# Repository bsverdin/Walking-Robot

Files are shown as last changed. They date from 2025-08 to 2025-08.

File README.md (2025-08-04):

# Walking-Robot
Walking robots for Science fair
In this repository, There are the codes for multiple robots: Model STU (initial prototype focused solely on energy-efficnecy), Model VINNIE (second prototype with a camera for easy operation), and MODEL TERRA (last prototype with a ultrasonic distance sensor).
All the walking robots operate on the Arduino IDE software system.
Model STU only uses an Arduino Uno board
Model VINNIE and MODEL TERRA uses two Espressif boards: The ESP32-CAM AI THINKER and the ESP32-WROOM

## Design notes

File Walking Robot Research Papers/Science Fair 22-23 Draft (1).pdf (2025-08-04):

# ABSTRACT

## The Illinois Junior Academy of Science Electronics

CATEGORY ________________________________________________________STATE REGION # ________________ Lane Tech College Prep

SCHOOL __________________________________________________________IJAS SCHOOL # _________________ Chicago / 60618 7735345400

CITY/ZIP __________________________________________________________SCHOOL PHONE ________________ Mr. Daniel Law

SPONSOR _________________________________________________________

CHECK ONE: ☐ EXPERIMENTAL INVESTIGATION [ ] ☐ DESIGN INVESTIGATION
(Choice will determine rubric used for assessment) Bianca Verdin

NAME OF EXHIBITOR * _______________________________________________GRADE________________________

NAME OF EXHIBITOR ________________________________________________GRADE _______________________

* If this project is awarded a monetary prize, the check will be written in this scientist’s name and it will be his/her responsibility to distribute the prize money equally among all participating exhibitors. Design of an Energy-Efficient Walking Robot

PROJECT TITLE ___________________________________________________________________________________ a) Purpose - The purpose of this design investigation was to create a walking quadruped robot that was energy-efficient. If walking robots were more energy efficient, they would be used for more exploration, search and rescue, and inspections. b) Procedure - The body of the robot was created using a 1 cm thick PVC board. After constructing the body, all the electronic components were screwed into the body. Then, using the code for last year, by implementing it to all the motors, the servos were then programmed to move in a specific gait. The robot's energy intake and distance traveled were used to calculate the Cost of Transportation (CoT) of the robot. c) Conclusion - While Design A may be more energy efficient, Design B is much more reliable and traveled longer distances than Design A. Design B was relatively energy efficient with a median cost of transportation of .14.

1. Limit Abstract to 3 paragraphs (250 words or less). Include: a) Purpose– what you set out to investigate; b) Procedure – how you did it;
c) Conclusion – based on your results. Label each paragraph.
2. Must be typed, single-spaced, on the front side of this form. DO NOT write on back side of this form.
3. Three (3) copies of your COMPLETE paper are required at the State Science Project Exposition. Four (4) copies of your COMPLETE paper are required for the State Paper Session Competition.

The above form must be duplicated. (Student-generated forms must be in essentially the same format.)
This form MUST be displayed on the front of the exhibitor’s display board. It may be reduced to fit on a half sheet of paper. (Print at 75% reduction) Displayed abstract cannot be smaller than 8.5 inches (vertical) x 5.5 inches (horizontal).

3

3001

(ALL ITEMS LISTED MUST BE TYPED)

SAVE Off | PRINT Off

SAFETY SHEET

The Illinois Junior Academy or Science Directions: The student is asked to read this introduction carefully, fill out the bottom of this sheet. The science teacher and/or advisor must sign in the indicated space. By signing this sheet, the sponsor
assumes all responsibilities related to this project.

Safety and the Student: Experimentation or design may involve an element of risk or injury to the student, test subjects and to others. Recognition of such hazards and provision for adequate control measures are joint responsibilities of the student and the sponsor. Some of the more common risks encountered in research al.e those of electi.ical shock, infection from pathogenic organisms, uncontrol]ed reactions of incompatible chemicals, eye injury from materials or procedures, and fire in apparatus or work area. Countering these hazards and others with suitable controls is an integral part of good scientific research. In the chart below,
list the principal hazards associated with your project, if any, and what specific precautions
you have used as safeguards. Be sure to read the entire section in the Po/I.cj/ fl,;!d P;.ocedwre A4lczj!#a/ a/ffee /J/I.iioz.a J"Hz.or .4cc}cJem); a/Sc.I.c#c.e entitled " Safety Guidelines for Experimentation" before completing this form.
Possible hazards | Precautions taken to deal with each hazard
1. Choking and hair loss are possible from
motors or power tools snagging on loose
articles or hair.
2. Overheating components could cause burns or fire.
3. Electrocution from an improper connection of wires.
4. Cuts and scratches from the pins, wires, and power tools.
5. Pedestrians and animals may hit the robot during outside testing.
1. Hair was tied back in a ponytail; no loose clothing, necklaces, or lanyards were worn, and all items with a hazard of getting caught were moved away from the motor.
2. Motors were tested in short trials no more than an hour and if the components got hot testing was immediately stopped.
3. All bent, broken, or uncovered wires were thrown away and not used to connect the motors.
4, Power tools were handled by adults only and any cuts and scratches sustained were immediately sanitized and treated.
5. Testing was immediately stopped when pedestrians or animals were spotted on the sidewalk

Please check off any other possible endorsements needed. Include these documents in your paper and on your board. Human as Test Subjects -for any projects involving humans-even surveys.
Microorganism-for any projects involving bacteria, viruses, yeasts, fimgi or protozoa -Non-Human Vcrtcbrates -for any projects involving fish, amphibians, rcpLilcs, birds or mammals
-Tissue Culture-for any proj ects involving growing eukaryotic tissues or cell cultures

Recombinant DNA-must be conducted in a regiLstered research laboratory under professi onal supervision
Use of Fircarms - including all required documents

## ±i_::tifutionwherel.esearchwasd;:,ZSZ%Xcept]:_nt°the]JAsm]esh::_:=L

*As a sponsor, I assume all responsibilities related to this project. This Sheet Must Be Typed and this form must be displayed on the front of the exhibitor's display board. Displayed Safety Sheet can not be smaller than 8.5 inches (vertical) X 5.5 inches qorizontal). Print at 75% reduction.

SAVE E | PRINT H

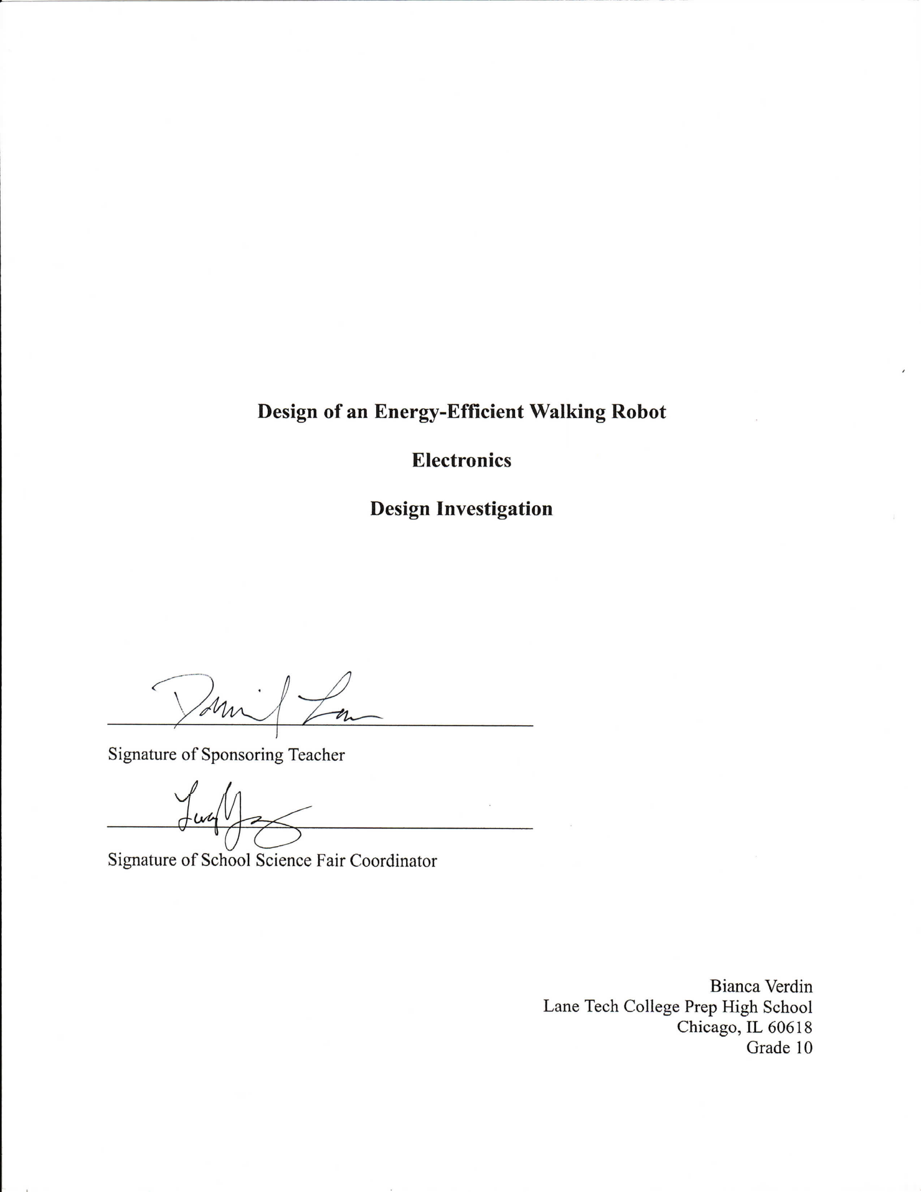
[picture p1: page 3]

### Design of an Energy-Efficient Walking Robot

Hlectronics

Design Investigation

Signature of Sponsoring Teacher

Signature of School Science Fair Coordinator

Bianca Verdin
Lane Tech College Prep High School Chicago, IL 606 1 8
Grade 10

Verdin: DESIGN OF AN ENERGY-EFFICIENT WALKING ROBOT | 4

Table of Contents

Acknowledgments

I would like to thank Mr. Law for agreeing to sponsor this project. I know it must’ve been

difficult because of the robotics club starting during this project and my understanding of only the bare

basics of robotics. My father, Salvador Verdin, helped me code and create the robot, and he also handled

the power tools. He sacrificed a lot of time to help me, and I appreciate that. Thank you to Charles

Petajan, my mentor, for helping me with my Background Research. Thank you to my mom, Griselda

Verdin, for helping me test the robot, as well as order the materials. I would like to thank Leila Miljkovic

from the Lane Tech Writing Center for looking over my rough draft. Thank you to Divinefavour Osuji, for

also looking at my draft and providing design-specific advice. Thank you to Ms. Young for pushing me to

complete this robot.

Definition of Need

Robots are now being used for search and rescue missions, mining, worksite inspections,

agriculture, and much more. The robots must deal with obstacles, such as steps, doors, or irregular terrain

(Bellicoso et al.). However, legged robots are less energy efficient than robots with wheels. According to

Xiao and Whittaker (2014), walking takes up 29% of a robot’s total energy usage. That is not factoring in

the energy needed for the robot’s computers, controllers, and means of communication to move the

motors. This means that a walking robot has to dedicate 71% of its energy to walking, an energy that

would normally go towards computing, like sensing its surroundings. It would need more energy to move

as long of a distance as a robot with wheels. This makes sense because walking robots need more motors

than wheeled robots. The energy consumption of the robot only gets worse as it walks, meaning that they

are often not seen as reliable enough to do certain tasks like, for example, space exploration, even though

it could improve certain aspects of how we explore other planets. During last year’s project, energy

consumption was a tremendous problem. The power source was not enough to power both the

microcontroller and multiple motors, however, the improvements of the code did slightly help to lower

how much energy each motor needed. Using the improvement to the code from last year, all the motors

will be connected to the Arduino and a strong enough power supply and create a body for the prototype of

the complete robot. The robot will be tested outside on the sidewalk. Then using the formula for specific

resistance, the cost of transportation will be calculated. The goal is for the robot to have an average cost of

transportation less than .15.

Background Research

Westcott (2020) said that electronics is "the study of devices that control the flow of electricity."

This subject covers concepts spanning from robotics to electrical engineering. The purpose of electrical

engineering is to research problems affecting current society and to design devices that improve on past

inventions. Smartphones, computers, and robots are all products of electrical engineering.

A challenge within electrical engineering is creating a robot that more naturally moves through

irregular terrain. Most robots use wheels to move around, limiting where the robot can go. However,

walking robots use legs to move, instead of wheels or tracks. Their legs provide easy mobility through

irregular terrain. Currently, Boston Dynamics has created LittleDog and Spot, two quadruped robots

designed after dogs. It is important for there to be walking robots because they can help with natural

disasters, such as pulling people out of the rubble, and they can complete tasks that are too dangerous for

humans, like exploring the terrain of Mars. People that might use a walking robot are researchers and first

responders, as the robots are able to go into smaller crevasses and can survive risky situations.While they

can be very helpful, they are often not practical in their consumption of power. According to Kashiri et al.

(2018), Big Dog has a Specific Resistance of 15 and so Big Dog can only run for 30 minutes in one full

15-liter tank of fuel. However, mammals have a power density of 0.041 W/g, meaning that robots still

have a long way to go when it comes to efficiency, especially compared to living things.

Discussion

Walking Robots

According to Wong et al. (2021), “a walking robot is a robot with legged locomotion." (2) This

means that instead of using wheels or tracks to move around, it uses legs controlled by several servo

motors to move around. This comes with multiple advantages which include the ability to move across

difficult terrain. Legs are less likely to get stuck in mud, dirt, grass, or any terrain where a wheel digs

itself in; legs also do less damage to the ground than tracks or wheels (Todd, 2013). However, walking

robots are very unstable. Teaching a robot to see and overcome obstacles is also difficult. For example, if

a walking robot has to climb steps, the robot must see the step and raise its legs to accommodate (Ortiz &

Vinjamuri, 2021). The robot will have one static gait because the stability of the robot is more important

than the speed of the robot. A gait is the relationship of animal limbs at a certain time and place. It

includes the regularly repeating pattern of when the limbs hit the floor and how the animal moves its

limbs. Quadruped robots have two groups of gaits, static and dynamic gait. Static gait means that the

center of the mass of the robot is always being held up by a triangle. It is very stable, however, it is also

very slow (Gong et al., 2018). Many gaits make the robot more or less stable. A creeping gait is when the

robot only lifts one leg at a time (Kajita & Espianu, 2008). Because it only raises one leg at a time, it is

always supported by that triangle, but is not the most efficient way to move. An understanding of gaits is

needed to code the motors in a way that not only allows the robot to walk stably. It also prevents the robot

from browning out (brownout is when the components of the robot take too much power from the

batteries at the same time and causes the robot to fail).

Biped vs. Quadruped Robots

There are multiple types of legged robots, such as bipedal and quadrupedal robots. Biped robots

have two legs and are usually humanoid. The center of mass is a lot higher than the center of mass of

most quadruped walking robots, which makes them more unstable. However, due to there being fewer

legs, depending on the robot, it can be more energy efficient than a quadruped robot. Quadruped robots

use four legs. There are two different quadrupeds: sprawling and mammal-type. The mammal type

quadruped is biologically inspired by mammals, for example, dogs or cats. The joints are underneath the

body of the robot and their limbs are shoulder-width apart. This type of robot is popular because of its

cost-efficiency. Sprawling-type quadrupeds are like spiders, but with fewer legs. The legs come up from

the body and then down towards the floor, and the distance between the limbs and the body is wider. This

makes the robot's center of mass lower, which gives the added benefit of the robot being more stable

(Kitano et al., 2016). There are other types of walking robots with more legs, such as hexapods, but they

are costly and less energy efficient. To sum it up, Gong et al., (2018) state that one-legged and biped

robots are not as stable and cannot carry the same amount as quadrupedal robots, and the experts and

other multi-legged robots structurally have an unnecessary amount of legs, which take up energy and add mass. This investigation influenced the design of the robot, as the pros and cons of each type of robot

were evaluated and the robot was made to be a mammal-like quadruped.

Current Innovations with Quadruped Robots.

Although there is more focus on the research of walking robots, they are not a new concept. The

first walking robot was invented in the 1800s by a man named Chebyshev and the first autonomous

quadruped robot was created in 1960 called the "phony pony" in California (Biswal & Mohanty, 2020).

The fastest quadruped robot has been the Cheetah by Boston Dynamics in 2013. They made a new mini

cheetah created by MIT in 2021, and it is the first to do a backflip (Zewe, 2021). This flexibility and

speed can be very useful, but its ability to leap is more fascinating, as it would allow the robot to get over

chasms or enormous obstacles it can't step over. Not only that, but it also uses a two-part controller; one

controller controls the robot while the other one is a neutral controller that takes in the ground's view and

"learns" from experience. The robot then gets both benefits of blind robots and improves on robots that

would need a map of the area first (Zewe, 2021). The new smallest walking robot is a microscopic

insect-like robot that has many gaits and can even jump (Morris, 2022). Its small build can be very helpful

in biology, especially in studying small ecosystems and insects. The most interesting thing, however, is

not its size, but the way it moves. It is not powered by any electricity or hardware. Instead, researchers

created a metal-like material that keeps its shape that it was bent into when heated and used it to create the

robot. Here, the researchers used a ray of light to quickly and repeatedly heat the robot, which made the

metal move. The scientist put glass on the robot to help the alloy return to its shape (Morris, 2022). The

TITAN series of robots have been a major source of inspiration for the robot. TITAN XIII, the newest

quadruped of the series, is a battery-powered sprawling quadruped robot that can walk efficiently at 1.38

m/s speed (Biswal & Mohanty 2020). Walking robots have proven their ability to be used in situations

such as inspections. The ANYmal was able to navigate through an oil site and measure different gauges,

and the position of valve handles. These inspections greatly improve the health and safety of the worksite

as well as improve efficiency and production (Bellicoso et al., 2018).

Energy Efficiency

Energy efficiency does not have a set definition or measurement, however, the usage of the word

that best fits the design is the ratio of the amount of useful output of a process compared to the amount of

energy input of the process (Patterson, 1996, p.377). Many experts view energy efficiency as being either

first-law efficiency (ratio of useful output to input) or second-law efficiency (based on the quality of the

output to the energy input) (Saunders et al., 2021). The issue becomes how to define the useful output and

energy input. Several indicators can track change in energy efficiency; they fall into Thermodynamic

(purely from thermodynamics), Physical-thermodynamic (energy input still measured in thermodynamic

units, but the output is measured in physical units), Economic-thermodynamic (output measured in terms

of market price), and Economic (purely market-based) (Patterson, 1996, p.377-378). For this robot, the

main measurement will be physical-thermodynamic based. Specific resistance measures the energy

efficiency of a robot. It is the ratio of the amount of energy over the gravitational potential energy that the

robot would have if it was raised off the ground by the distance walked. (E/Mgd) This is equivalent to the

Cost of Transportation (Kajita & Espianu, 2008). The reason for this formula is that the total energy used

for moving varies on the mass, the gravity, the distance, and even the amount of friction on the surface

walked (Xiao & Whittaker, 2014). The robot will be tested on the same floor over all trials, so friction of

the floor is less of a problem. There have been many designs to lower the energy consumption of walking

robots. Many robots take inspiration from real life. These are biologically inspired robots. One robot,

made by Wong et al., uses springs up and down the robot's legs to replicate how live things absorb the

shock of stepping. However, even robots biologically inspired are not as efficient as animals or people.

The Walkman robot shows a maximum consumption of 368 W, having an SR of 1.35. The SR is seven

times higher than a person walking. (Kashiri et al.)

Servo Motors

Servo motors are motors which can be controlled to move to specific angles. There are motors

with 180 rotation and continuous rotation. Servos are controlled by pulses through the signal. "For a

normal servo, sending a 1 ms 5v pulse turns the motor to 0 degrees, and sending a 2 ms 5v pulse turns the

motor to 180 degrees." (Blum, 2019, 102) Servo motors differ from your average DC motor, as not only can you specifically position the motor, but the servo motor has three pins, one for ground (brown), one

for power (red), and one for signal (yellow/orange). (Blum, 2019, 102) A problem that occurred in the

initial design was the motors shaking uncontrollably and attaching multiple motors would cause the

motors to rattle and stop. The reason this happened was that the Arduino Uno takes 5v and each servo

motor takes 4.8v to 6v. Because all the motors were pulling power and the microcontroller, the cable that

was providing the power could only supply enough voltage for the microcontroller. This can cause servos

to "jitter". (Bräunl, 2013). Another way to avoid the "jitters" through the program is to add slight delays

between the calls for each servo. This will increase servo torque. (Bräunl, 2013) This information is

important, as this problem was prevalent in both previous year’s work, and this year’s work, and when it

“jitters”, it causes a surge in the amount of energy use, which must be prevented.

Powering the Robot

A battery is the best option to provide enough power for all the motors and microcontrollers. A

battery is made of multiple cells in a series and comprises three parts: two electrodes (anode and cathode),

and an electrolyte. (Beam et al., 2017) There are two types of batteries, rechargeable, and

non-rechargeable. The rechargeable batteries can reverse the current to charge themselves.

Non-rechargeable and rechargeable batteries both have their advantages. Non-rechargeable batteries have

higher capacity, but once they run out of power, change the batteries, which will become more costly,

especially if the batteries drain quickly. Rechargeable batteries don't have high capacities, but

rechargeable batteries will save money later. Devices that quickly drain batteries often use rechargeable

batteries, while low-drain devices use normal batteries. (Beam et al., 2017) With the batteries, there will

also be a capacitor. A capacitor comprises two plates that can conduct electricity; sandwiched in between

the plates is some sort of insulant. (Brindley, 2016, 58) The capacitor would store extra voltage from the

battery. When the robot is consuming an outrageous amount of energy, the capacitor will release the

stored energy to help there not be a shortage of power. This project uses an electrolytic capacitor, also

known as a polarized capacitor. The electrolytic capacitor is named after the fact that it uses electrolysis to

capacitate. This electrolytic action means that it is polarized, unlike most capacitors. (Brindley, 2016, 58)

The reason the capacitor is needed in the first place is because of Ohm's law. Westcott (2020) defines

Ohm's law as, "Ohm's Law states that the current (I) between two points is directly proportional to the

voltage (V) and inversely proportional to the resistance (R). As an equation, it is written I = V/R". (19)

The current isn't proportional to the voltage or inversely proportional to the resistance, but the capacitor

will reduce the resistance, making everything proportional. This investigation was critical to the design,

as, before the understanding of Ohm's law and energy efficiency, the robot experienced a serious

brownout and overheating, almost destroying the microcontroller.

Related Studies

One inspiration for the robot was Ranger. Bhounsule et al. (2012) made Ranger, which walked

40.5 miles completely on its own on a single charge, taking 30 hours, 49 minutes, and 2 seconds, setting a

record for robot distance, and it walked at an average Cost Of Transportation of 0.19, which is less than

any other legged robot at the time. Ranger has long legs, but does not have knees, instead, he has joints on

his ankles, and his legs swing to walk. Its unique 4-legged biped design has it walk similar to a gorilla.

The purpose of the study was to create an energy efficient robot that wouldn’t fall down as often. The

ankle joints were something from Ranger that was originally implemented to this design investigation.

However, with the size and amount of energy that the motors took, it was not practical. Instead, I slightly

implemented the foot shape of Ranger to create the rocking motion that the legs would need to walk.

Another important study of the development of the robot was the ANYmal. According to Hutter

et al. 2016, the ANYmal is a quadrupedal robot that has a lot of range and mobility. The joint modules

make the robotic dog’s torque controllable and able to withstand the load on the motors during running or

jumping. It was stable outdoors, easy to maintain, and user-friendly. ANYmal had different gaits and

speeds that it could use and it can stand up or crawl up very steep stairs. The robot can run for 2 hours

completely autonomously. Both of these studies are examples of very energy-efficient robots. Ranger and

the ANYmal were both able to run long distances on a single charge. These robots set a standard of what

should be expected from an energy-efficient robot. They also inspired many aspects of the design of the

robot, such as the feet shape and the initial design of the legs.

Conclusion

For now, the energy efficiency of walking robots pales in comparison to wheeled robots or living

things. Many designs for a more energy efficient robot have been made, in hopes that they will be used

for research or rescue. There should be more research on ways to map out an area during an autonomous

run. Designs like the Cheetah have attempted to resolve this issue, however, none have seemingly been

able to quickly scan an area and react to it completely autonomously. This design benefited from the

research on the cost of transportation and Ohm's law. Understanding the meaning behind the cost of

transportation and how to measure it will help to compare to previous designs and if the design improved,

both on the robot and other robots previously made by others. Research on Ohm's law was relevant as the

high-draining motors would often pull too much power and cause a brownout. Using Ohm's law,

improvements in the design, especially the connection of the capacitor and the type of battery used for the

robot, significantly lowered the chances of the robot experiencing a brownout. In the future, more

research on self-correcting autonomous robots will have to be made to correct the drift that the robot

experiences.

Materials

- 9 Miuzei SG90 servo motors with servo

horns

- 1 Arduino Uno
- 1 toggle switch
- 1 polarized capacitor 4700μF
- 4 1.5v keeppower rechargeable batteries
- 1 cm thick PVC board
- 22 gauge wire
- 1 laptop
- 1 A male to B male printer cable
- 6 x 3/4 in. flathead Phillip screws
- 1 #0 Phillip screwdriver
- 22 #0-80 x ¾ in. Panhead Phillip screws
- 9 #0-80 x 1/8 in. Panhead Phillip screws
- 1-2 Hot glue sticks
- 1 Hot glue gun
- 1 drill with a Philip drill bit
- 1 Circular saw
- 1 jigsaw
- 1 battery mount with 4 cells
- 2 25-pin circuit boards
- PVC glue
- 1 toothpick
- 1 roll of electrical tape
- 1 roll of masking tape
- 1 stopwatch
- 1 scale
- 1 multimeter

Design Plan

The robot can not take up over 4 1.5v batteries. It must remain relatively small and light, as the

bulkiness and weight would add extra strain to the motors, which will cause them to pull more power

from the battery to complete the step. The goal of the design is to run on the batteries for more than an

hour.

Table 1.1

Design Criteria | What Makes Up this Design Criteria | Importance on a Scale of 1-5
Functionality | ● The robot is able to walk for at least 10 secs ● The robot walks in a straight line, unless the axis is changed from set position | 5
Energy-Efficiency | ● The robot has a median cost of transportation of around .15 or less ● The cost of transportation is precise | 4

Table 1.1 shows the design criteria of the walking quadruped robot.

Part A: Assembling the Robot

Figure 1.1

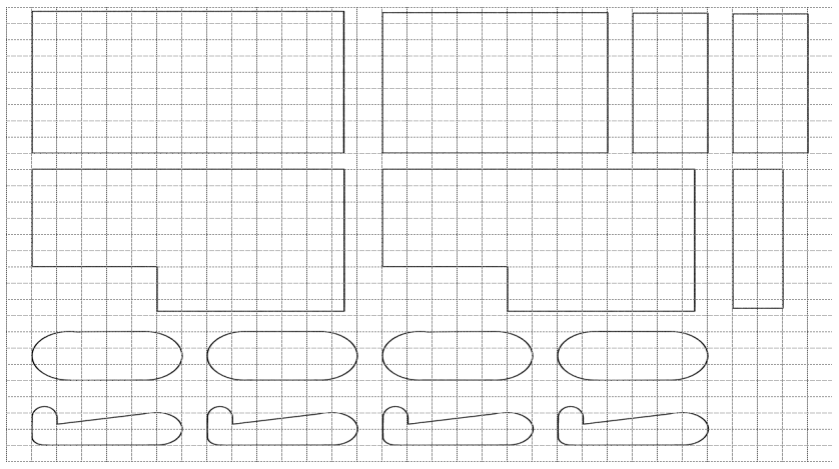
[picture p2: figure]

Figure 1.1 shows the pieces cut out of the 1cm thick PVC board, with each square being equal to 1cm² .

Figure 1.2

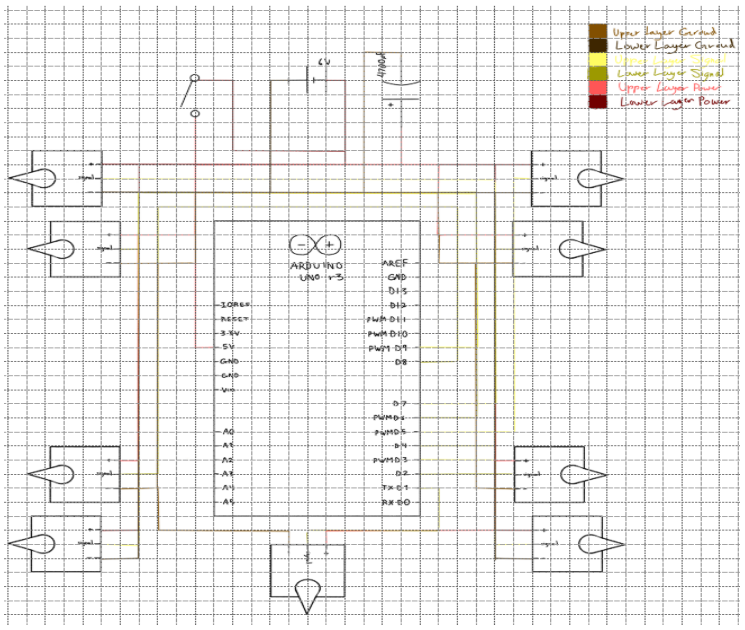
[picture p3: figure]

Figure 1.2 is a circuit schematic of the walking robot.

1. Cut out the pieces shown in figure 1.1 with the dimensions shown out of the PVC board.
2. Attach the servo motors to the holes with two #0-80 x ¾ in. pan head Phillip screws per servo

motor

3. Attach the 12.5cm x 9.2cm piece to the two “L” pieces on the longer side that faces towards the

floor and the 3.2cm x 9.2cm piece using 8 6 x 3/4 in. flathead Phillip screws.

4. Attach the 7.5cm x 9.2cm piece parallel to the 3.2cm x 7.5cm piece to the smaller end of the "L"

pieces using 6 6x3/4 in. flathead Phillip screws.

5. Attach the two 7.5cm x 3.5cm pieces using the PVC glue and 4 6 x 3/4 in. flathead Phillip screws.

6. When dried and bonded, carve out 1.3cm x 2.2cm x 1.1cm holes on both ends of the piece using

the jigsaw.

7. Attach the two-pong servo horn to the 7.5cm x 3.5cm using two #0-80 x1/8 in. Panhead Phillip

screws.

8. Attach the servo horn and PVC to the servo attached to the 12.5cm x 9.2cm piece using a #0-80

x1/8 in. Panhead Phillip screw.

9. Attach the circuit boards to the robot using PVC glue.
10. Attach the Arduino board's plastic cover using 4 #0-80 x ¾ in. pan head Phillip screws.
11. Carve out holes for wires with the jigsaw in the "L" pieces, at the bottom of the robot, in the

battery space, and a small hole for each motor at the top of each leg segment.

12. Cut off the prongs of 8 servo horns until only the circular piece is left.
13. Hot glue the circular pieces into the top hole of each leg segment, unclogging the hole with a

toothpick. This will allow for easy access later.

14. Screw the leg segments to the motors, with the smooth round pieces at the top, and the smaller

pieces with a foot at the bottom go on the bottom using #0-80 x1/8 in. Panhead Phillip screws for

each hole.

15. Hot glue extra wire to the edges of the legs, battery space, and axis.
16. Attach the wires, capacitor, toggle switch, and batteries to the Arduino as shown in Figure 1.2

Part B: Coding the Robot

1. Create a new file in the Arduino IDE program.
2. Like in the last program, you will write “#include <Servo.h>” first.
3. Write “Servo” followed by the names of your motor. Repeat for every motor. For organization,

the motors are named Axis 1, Shoulder 1, Elbow 1, Shoulder 2, Elbow 2, Hip 3, Knee 3, Hip 4,

and Knee 4.

4. Write the initial variables of each motor. There is no certainty that the motors would be placed

perfectly in the robot so that 0 points towards the floor. The variables will differ based on the

placing of the motors, but at the end, it should point straight down to the floor.

5. Write int variables for some delay. d1= 500, d2=1000, d3=50, d4=75, d5=100, and d6=3000.
6. In void setup() {}, between the brackets write the motors and attach them. For example,

“axis1.write(a1); axis1.attach(1);” The order matters here, as it will help the robot stand. The

pattern is axis1, hip3, shoulder 1, hip 4, shoulder2, knee3, elbow1, knee4, elbow2. Write the int

position from earlier in the () of the .write. Do not forget the delays in between. The first four

delays are d1, and the three after that are d2. The last one is d6.

7. Still under void setup() {}, write shoulder2.write(s2-30);, delay(d5);, knee4.write(k4+60);,

delay(d5);, hip4.write(h4-30);, delay(d5);, elbow1.write(e1-60);, delay(d5);,

shoulder1.write(s1+30);, delay(d5);, knee3.write(k3-60);,delay(d5);, hip3.write(h3+30);, and

delay(d6);. The numbers added/subtracted affect the position of the robot for walking, as it cannot

walk as well with straight legs. These numbers will be the opposites of each other because of

what side they are on.

8. Create a new function called void walk1() {};
9. In void walk1() {}, between the brackets write shoulder2.write(s2-30);, hip3.write(h3+30);,

delay(d5);, knee3.write(k3-60);, elbow2.write(e2+60);, delay(d5);, knee4.write(k4+70);,

elbow1.write(e1-70);, delay(d5);, shoulder1.write(s1);, hip4.write(h4);, delay(d5);,

knee4.write(k4+20);, elbow1.write(e1-20);, delay(d5);, shoulder1.write(s1+30);,

hip4.write(h4-30);, delay(d5);, knee4.write(k4+60);, elbow1.write(e1-60);, and delay(d5);.

10. Upload to the Arduino using the A male to B male printer cable to connect the Arduino to the

laptop.

Part C: Testing the Robot

1. Mass the robot in kilograms.
2. Fully charge the batteries.

3. Measure the amps of the batteries.
4. Put some masking tape on the floor at the beginning of the hallway
5. Turn on the robot and place it on the floor behind the masking tape
6. Let the robot run in a straight line until it collapses.
7. Put tape where the robot collapsed.
8. Measure the amps of the robot again.
9. Measure the time and distance that the robot traveled.
10. Calculate the Cost of Transportation using the E/Mgd equation, with g being equal to 9.8 m/s

2
11. Repeat for three trials for the three designs.

Design Results

Table 1.2

Cost of Transportation of Design A Design A

Distance (m)

Energy Used
(V) CoT
Trial 1 | 0.10 | 5.47 | 0.01
Trial 2 | 0.54 | 5.59 | 0.04
Trial 3 | 1.20 | 5.35 | 0.08
Trial 4 | 0.14 | 5.21 | 0.00
Trial 5 | 1.02 | 5.53 | 0.00
Mean | 0.60 | 5.43 | 0.03
SD | 0.45 | 0.14 | 0.03
SE | 0.26 | 0.08 | 0.02
Table 1.2 shows the distance walked in meters, the energy used in volts and the cost of transportation

across five trials.

Figure 1.3

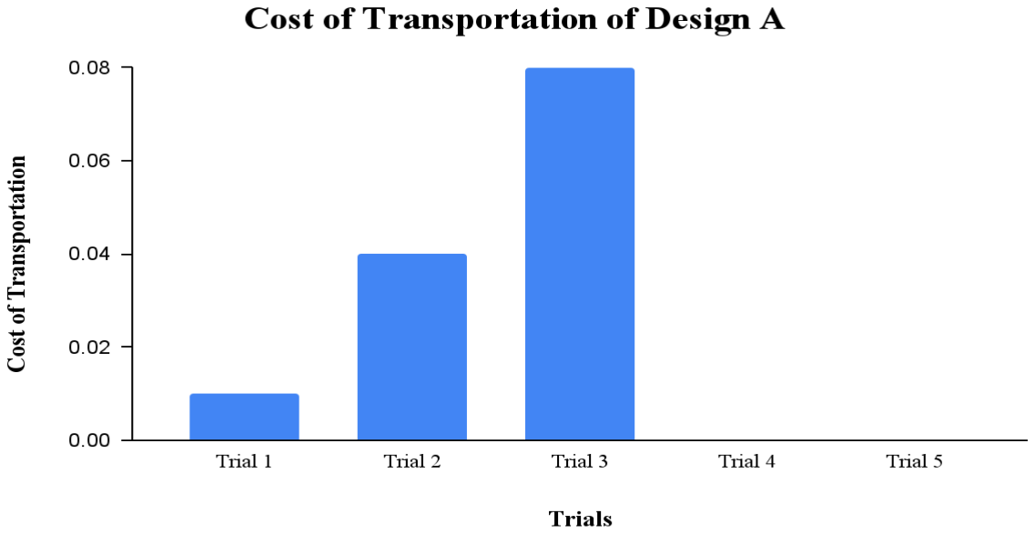
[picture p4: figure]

Figure 1.3 shows the cost of transportation of Design A through five trials.

Table 1.3

Design Criteria | What Makes Up this Design Criteria | Completion of on a Scale of 1-5
Functionality | ● The robot is able to walk for at least 10 secs ● The robot walks in a straight line, unless the axis is changed from set position | 2
Energy-Efficiency | ● The robot has a median cost of transportation of around .15 or less ● The cost of transportation is precise | 5

Table 1.3 shows the completion of the design criteria for Design A.

Redesign Plan

Although the cost of transportation for Design A was low, there was a severe problem with the

gait. The robot would not walk straight. Instead it would buck back and forth, often moving sideways

instead of forward. One thing that could have caused the robot’s jerking movement was the rapid

movement of the motor. When the motor was called, the motor would instantly move to the new position.

The delays only slightly fixed this issue. The best way to fix this was to create for functions that would

make sure that the motors would slowly get to the new position a few degrees at a time.

Part D- Redesigning the Code

1. Create a new function called void walk3() {};
2. In void walk3() {}, between the brackets, insert for (m = 0; m <= 12; m += 1) {};
3. In the brackets of the for function, write: knee3.write(k3-60-m); delay(0);

elbow2.write(e2+60+m); delay(15);

4. Write another for function for (m = 0; m <= 30; m += 1) {};
5. In the brackets for the second for function, write: shoulder2.write(s2-30+m); delay(0);

hip3.write(h3+30-m); delay(15);

6. Insert function for (m = 0; m <= 24; m += 1) {};
7. In the brackets, write: knee3.write(k3-72+m); delay(0); elbow2.write(e2+72-m); delay(15);
8. Insert for (m = 0; m <= 30; m += 1) {}
9. Write in the brackets of the for function: shoulder2.write(s2-m); delay(0); hip3.write(h3+m);

delay(15);

10. Write for (m = 0; m <=12; m += 1){};
11. In the brackets, write: knee3.write(k3-48-m); delay(0); elbow2.write(e2+48+m); delay(15);
12. Write for (m = 0; m <= 12; m += 1) {};
13. In brackets, write: knee4.write(k4+60+m); delay(0); elbow1.write(e1-60-m); delay(15);

14. Write for (m = 0; m <= 30; m += 1) {};
15. In brackets, write: shoulder1.write(s1+30-m); delay(0); hip4.write(h4-30+m); delay(15);
16. Write for (m = 0; m <= 24; m += 1) {};
17. In brackets, write: knee4.write(k4+72-m); delay(0); elbow1.write(e1-72+m); delay(15);
18. Write for (m = 0; m <= 30; m += 1) {};
19. In the brackets, write: shoulder1.write(s1+m); delay(0); hip4.write(h4-m); delay(15);
20. Write for (m = 0; m <=12; m+= 1){};
21. In brackets, write: knee4.write(k3+48+m);delay(0); elbow1.write(e2-48-m);delay(15);

Redesign Results

Table 1.4

Cost of Transportation of Design B Design B

Distance (m)

Energy Used
(V) CoT
Trial 1 | 6.44 | 5.89 | 0.38
Trial 2 | 2.15 | 5.32 | 0.14
Trial 3 | 2.09 | 5.67 | 0.15
Trial 4 | 1.54 | 5.58 | 0.00
Trial 5 | 1.65 | 5.71 | 0.00
Mean | 2.77 | 5.63 | 0.13
SD | 1.85 | 0.19 | 0.14
SE | 1.07 | 0.11 | 0.08

Table 1.4 shows the distance in meters, the energy used in volts, and the cost of transportation across five

trials.

Figure 1.4

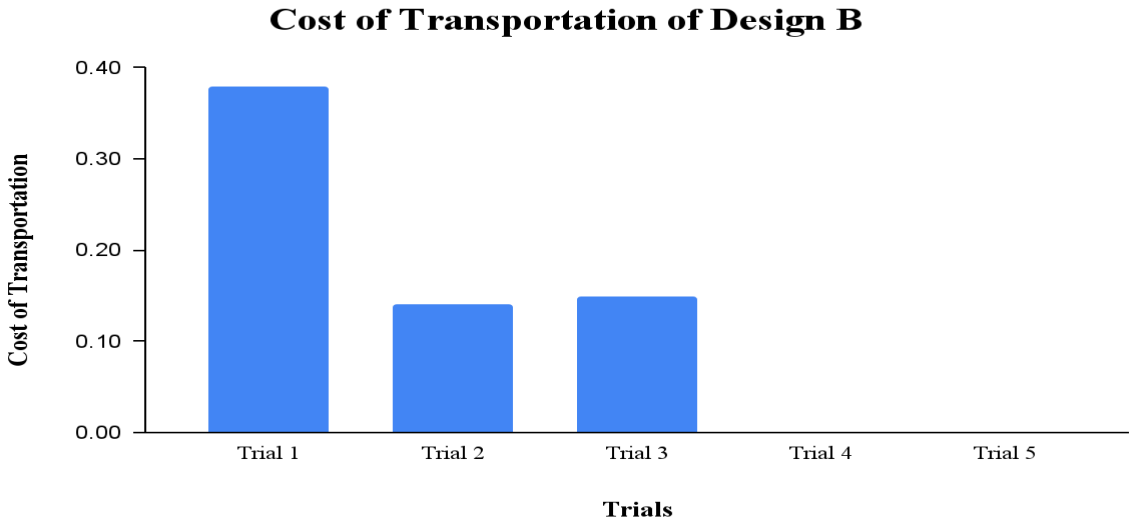
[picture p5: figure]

Figure 1.4 shows the cost of transportation of Design B across five trials.

Table 1.5

The Effect of Distance (m) and Energy Used (V) on Cost of Transportation
| | Design A | | | Design B
| Distance
| (m) | Energy
| | Used (V) | CoT | Distance
| | | | (m) | Energy
| | | | | Used (V) | CoT
Trial 1 | 0.10 | 5.47 | 0.01 | 6.44 | 5.89 | 0.38
Trial 2 | 0.54 | 5.59 | 0.04 | 2.15 | 5.32 | 0.14
Trial 3 | 1.20 | 5.35 | 0.08 | 2.09 | 5.67 | 0.15
Trial 4 | 0.14 | 5.21 | 0.00 | 1.54 | 5.58 | 0.00
Trial 5 | 1.02 | 5.53 | 0.00 | 1.65 | 5.71 | 0.00
Mean | 0.60 | 5.43 | 0.03 | 2.77 | 5.63 | 0.13
SD | 0.45 | 0.14 | 0.03 | 1.85 | 0.19 | 0.14
SE | 0.26 | 0.08 | 0.02 | 1.07 | 0.11 | 0.08
Table 1.5 shows the distance, energy used, and cost of transportation of design A and design B.

Figure 1.5

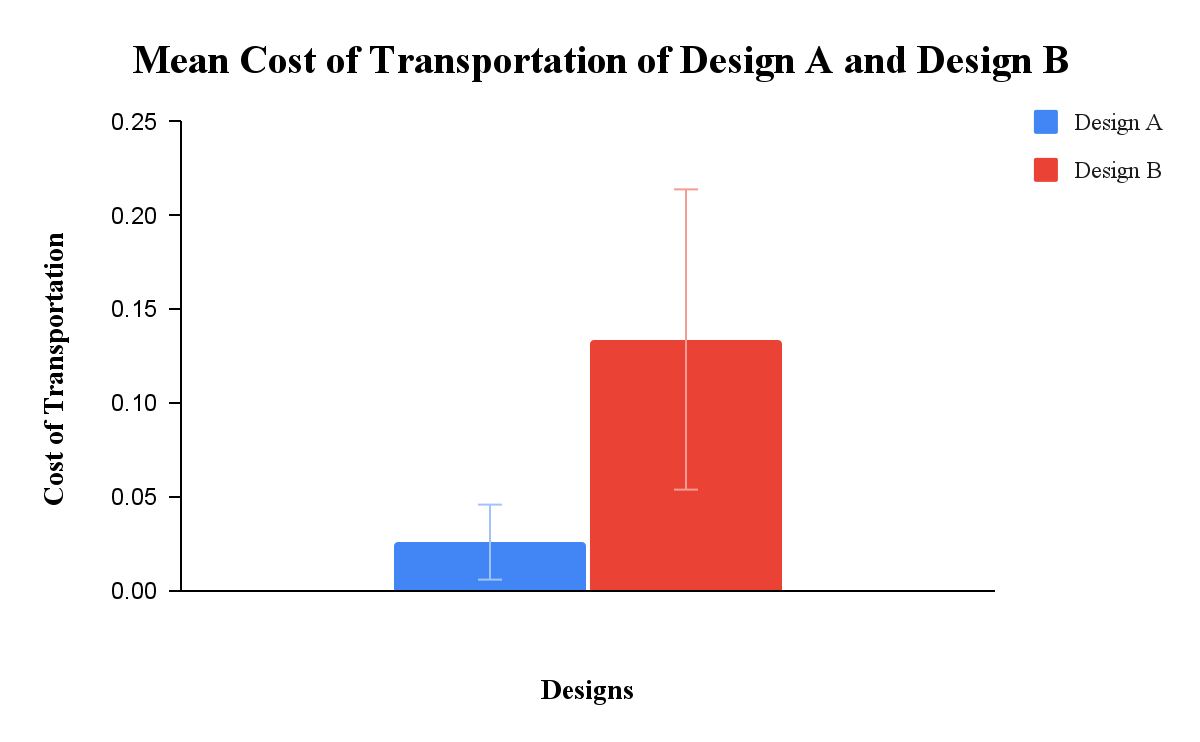
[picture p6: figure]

Figure 1.5 shows the mean cost of transportation between the two designs.

Table 1.6

Design Criteria | What Makes Up this Design Criteria | Completion of on a Scale of 1-5
Functionality | ● The robot is able to walk for at least 10 secs ● The robot walks in a straight line, unless the axis is changed from set position | 4
Energy-Efficiency | ● The robot has a median cost of transportation of around .15 or less ● The cost of transportation is precise | 4

Table 1.6 shows the completion of the design criteria for Design B.

Conclusion

The redesign improved the distance achieved by the robot, however, the average cost of

transportation was affected negatively by the redesign. One reason for this could be that the for function

has the motors pull less energy, but it's over more time, and because the motors are moving two at a time,

versus the one-at-a-time movement of Design A, this caused the motors to pull more energy from the

robot, with negatively affected their cost of transportation. However, Design A could barely walk, as it

was jumping in all directions and could not move stably in one direction. By this logic, the poor

performance of the robot should have negatively affected the cost of transportation, however, when the

calculations were made, the robot was given a very low cost of transportation, even giving costs of

transportation of 0.0 for both Designs A and B during Trials 4-5. These costs of transportations are

probably an error. However, the more realistic scores of Design B were very good as well, especially in

Trials 2-3, with scores of .14 and .15 respectively. Because of the higher cost of transportation in Trial 1

and the scores given to Design A being impossibly low, the average cost of transportation seems a lot

higher than it was.

There were many errors in this investigation. For example, the robot does not walk in a straight

line, so the distance measurements are not perfect, especially in Trial 1 of Design B, as the robot walked

in a circle and then continued in a straight line as before, and the circle affected the accuracy of the

distance the robot walked. The cause of the robot walking in a circle is unknown, and the robot hasn't

done it since the first trial. The problem is also shared with all of Design A, with its jerking back and forth

messing up the distance, as seen with the high standard errors of the distances (0.26 for Design A and

1.07 for Design B). Next year, the robot will have gyros attached to it to keep the robot in a straight line.

The purpose of this robot was to create an energy-efficient robot so that it would be more reliable

for certain tasks which may not allow for the robot to be frequently recharged or constantly draining

energy. However, as this design investigation shows, the cost of transportation is only a part of the

equation of a reliable, energy-efficient robot. For example, Design A may be energy efficient but not

reliable. Either way, the robot reached its goal of being relatively energy-efficient and reliable. However, many more changes can be made to improve the robot's reliability. Next year, the robot will become

autonomous, making it easier to complete tasks without human control or supervision, as needed for any

useful real-world applications.

Reference List

Beam, R, Wilkin, M. K., Kuszynski, J.,& Darensbourg M. Y. (2017) Batteries: rechargeable vs.

non-rechargeable batteries. Texas A&M

University.https://www.chem.tamu.edu/rgroup/marcetta/chem362/HW/2017%20Student%20Post

ers/Batteries-%20Rechargeable%20vs.%20Non-rechargeable%20Batteries.pdf

Bellicoso, D., Bjelonic, M., Wellhausen, L. & Holtmann, K. (2018) Advances in real-world applications

for legged robots. Journal of Field Robotics. DOI:10.1002/rob.21839

Bhounsule, P. A., Cortell, J., & Ruina, A. (2012). Design and control of ranger: An energy efficient,

dynamic walking robot. Adaptive Mobile Robotics, 441–448.

https://doi.org/10.1142/9789814415958_0057

Biswal, P. & Mohanty P. K. (2020). Development of quadruped walking robots: A review. Ain Shams

Engineering Journal, 12(2).https://doi.org/10.1016/j.asej.2020.11.005

Bräunl, T (2013) Embedded robotics: Mobile robot design and applications with embedded systems.

Springer Berlin

Heidelberghttps://www.google.com/books/edition/Embedded_Robotics/5rntCAAAQBAJ?hl=en

&gbpv=0

Brindley, K. (2016) Starting electronics: All you need to get a grounding in practical electronics. Elsevier

Science. https://www.google.com/books/edition/_/PQP9BAAAQBAJ?hl=en&gbpv=0

Blum, J. (2019) Exploring arduino: Tools and techniques for engineering wizardry.

Wiley.https://www.google.com/books/edition/Exploring_Arduino/XQm5DwAAQBAJ?hl=en&gb

pv=0

Gong, D., Wang, P., Zhao, S., Du, L. & Duan, Y. (2018) Bionic quadruped robot dynamic gait control

strategy based on twenty degrees of freedom. IEEE. 10.1109/JAS.2017.7510790

Hutter, M., Gehring, C., Jud, D., Lauber, A., Bellicoso, C. D., Tsounis, V., Hwangbo, J., Bodie, K.,

Fankhauser, P., Bloesch, M., Diethelm, R., Bachmann, S., Melzer, A., & Hoepflinger, M. (2016).

ANYmal:A highly mobile and dynamic quadrupedal robot. 2016 IEEE/RSJ International

Conference on Intelligent Robots and Systems (IROS). https://doi.org/10.1109/iros.2016.7758092

Kajita, S. & Espiau, B. (2018) Legged Robots. Handbook of robotics. (361-389) Springer.

978-3-319-32552-1

Kashiri et al. (2018) An Overview on Principles for Energy Efficient Robot Locomotion. Advances in

Mechatronics and Biomechanics towards Efficient Robot Actuation.

https://doi.org/10.3389/frobt.2018.00129

Kitano, S., Hirose, S., Horigome, A. & Endo, G. (2016) Titan-XIII: Sprawling-type quadruped robot with

ability of fast and energy-efficient walking. ROBOMECH Journal, 3(8).

https://doi.org/10.1186/s40648-016-0047-1

Morris, A. (2022) Tiny robotic crab is smallest-ever remote-controlled walking robot. Northwestern.

https://news.northwestern.edu/stories/2022/05/tiny-robotic-crab-is-smallest-ever-remote-controlle

d-walking-robot/

Ortiz, J. H. & Vinjamuri R. (2021) Collaborative and humanoid robots. Intech Open.

https://www.google.com/books/edition/_/GtJGEAAAQBAJ?hl=en&gbpv=0

Patterson, M. (1996) What is energy efficiency? Concepts, issues and methodological issues. Energy

Policy,

24(5).https://www.researchgate.net/publication/222171789_What_is_energy_efficiency_Concept

s_issues_and_methodological_issues

Saunders, H. et al. (2021) Energy efficiency: What has research delivered in the last 40 years? Annual

Review of Environment and Resources,

46.https://doi.org/10.1146/annurev-environ-012320-084937

Todd, D. J. (2013). Walking machines. Springer

US.https://www.google.com/books/edition/Walking_Machines/zb_SBwAAQBAJ?hl=en&gbpv=0

Westcott, S., & Westcott J. R. (2020) Basic electronics: Theory and practice. Mercury Learning and

Information.https://www.google.com/books/edition/Basic_Electronics/mkbrDwAAQBAJ?hl=en

&gbpv=0

Wong, L. H., Sivanesan, S., M F A Faisol, Othman, W., Wahab, A. & Alhady, S. (2021) Development of

quadruped walking robot with passive compliance legs using XL4005 buck converter. Journal of

Physics: Conference Series, 1969(), 26-27. https://doi.org/10.1088/1742-6596/1969/1/012003

Xiao, X. & Whittaker, W. L. (2014) Energy considerations for wheeled mobile robots operating on a

single battery discharge. Carnegie Mellon University.

https://www.ri.cmu.edu/pub_files/2014/8/TR-14-16.pdf

Zewe, A. (2021). One giant leap for the mini cheetah: A new control system, demonstrated using MIT’s

robotic mini cheetah, enables four-legged robots to jump across uneven terrain in real-time. MIT

News. https://news.mit.edu/2021/one-giant-leap-mini-cheetah-1020

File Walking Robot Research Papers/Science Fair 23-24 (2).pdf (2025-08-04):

Design of an Exploration Walking Robot

Electronics

Design Investigation

_______________________________________________

Signature of Sponsoring Teacher

_______________________________________________

Signature of School Science Fair Coordinator

Bianca Verdin
Lane Tech College Prep High School Chicago, IL 60618
Grade 11

Verdin: DESIGN OF AN EXPLORATION WALKING ROBOT | 4

Table of Contents

Acknowledgments

Firstly, I would like to thank all my judges from the Lane Tech, Regional, and City

STEM Exhibitions, for providing me with genuine feedback on my project last year. I would also

like to thank my parents, Salvador Verdin and Griselda Verdin, for ordering materials and

making sure I always had the resources to complete my design. I would also like to apologize to

my little brother, Joel Verdin, for the hours of sleep lost due to the 3D printer in his room running

all night. Thank you to Divinefavor Osuji, for advising me to upload my code onto a Github

repository. Thank you to Mr. Robert Berg, the Lane Tech Robotics Team’s coach, for sponsoring

my project. And thank you to Mr. Daniel Law, another robotics coach, and my sponsor for last

year, for recommending me to Mr. Berg. Go team #4645!

Definition of Need

Robots are now being used for search and rescue missions, mining, worksite inspections,

agriculture, and much more. The robots must deal with obstacles, such as steps, doors, or

irregular terrain (Bellicoso et al., 2018). As companies such as NASA begin to use walking

robots to explore into caves, there is a market for walking robots. According to Xiao and

Whittaker (2014), legged robots are less energy-efficient than robots with wheels. This means

that the amount of time per mission and the distance that the new walking robots will go will be

less than a wheeled rover. Also, many of these cave exploring machines are very large and need

long periods of training to control. This is an issue, as it might restrict which caves can be

explored. A portable, easy to control and energy-efficient quadruped robot would allow for

greater cave exploration and could be easily applied to search and rescue, inspections, and other

types of exploration. This design investigation will use the electronic layout and gait from last

year’s prototype to create a walking robot fit for exploration purposes. The robot uses two

microcontrollers. One acts as the Wi-Fi access point and the camera, the other controls the servo

motors. Using a computer connected to the Wi-Fi access point, the website controls the robot by

sending information to the camera, which then uses the ESP-NOW protocol, which is unique to

this brand of microcontrollers, to send the information to the microcontroller that controls the

servo motors. The camera also provides feedback to the website via the stream, allowing the user

to see what the robot sees.

Background Research

According to Westcott (2020), electronics include controlling the flow of electricity. This

subject covers concepts spanning from robotics to electrical engineering. The goal of electrical

engineering is to investigate current societal problems and design, build, and test electrical

devices that usually improve on previous innovations. Smartphones, computers, and robots are

the products of electrical engineering.

One challenge electrical engineers are now facing is designing a robot that can navigate

irregular terrain. Most robots use wheels to move around, limiting where the robot can go.

However, walking robots instead utilize their legs to move. Their legs provide easy mobility

through rough terrain. Currently, Boston Dynamics has created LittleDog and Spot, two

quadruped robots designed after dogs. Walking robots can help save lives in disasters and

explore risky areas. Researchers and first responders can benefit from using a walking robot.

These robots can navigate tight spaces and handle dangerous situations. While they can be very

helpful, they are often not practical in their consumption of power. According to Kashiri et al.

(2018), Big Dog has a Specific Resistance of .15, so Big Dog can only run for 30 minutes in one

full 15-liter tank of fuel. Robots still have a long way to go when it comes to efficiency,

especially compared to living things.

Discussion

Walking Robots

According to Wong et al. (2021), “a walking robot is a robot with legged locomotion.”

(2) This means that instead of using wheels or tracks to move around, it uses legs controlled by

several servo motors to move around. This comes with multiple advantages, which include the

ability to move across difficult terrain. Legs are less likely to get stuck in mud, dirt, grass, or any terrain where a wheel digs itself in; legs also do less damage to the ground than tracks or wheels

do (Todd, 2013). However, walking robots are very unstable. Teaching a robot to see and

overcome obstacles is also difficult. For example, if a walking robot has to climb steps, the robot

must see the step and raise its legs to accommodate (Ortiz & Vinjamuri, 2021). The robot will

have one static gait because the stability of the robot is more important than the speed of the

robot. A gait is the relationship of animal limbs at a certain time and place. It includes the

regularly repeating pattern of when the limbs hit the floor and how the animal moves its limbs.

Quadruped robots have two groups of gaits, static and dynamic gait. Static gait means that the

center of the mass of the robot is always being held up by a triangle. It is very stable, but it is

also very slow (Gong et al., 2018). Various gaits make the robot more or less stable. A creeping

gait is when the robot only lifts one leg at a time (Kajita & Espianu, 2008). Because it only raises

one leg at a time, that triangle always supports the robot but is not the most efficient way to

move.

Biped vs. Quadruped Robots

There are multiple types of legged robots, such as bipedal and quadrupedal robots. Biped

robots have two legs and are usually humanoid. The center of mass is a lot higher than the center

of mass of most quadruped walking robots, which makes them more unstable. However, due to

there being fewer legs, depending on the robot, it can be more energy-efficient than a quadruped

robot. Quadruped robots use four legs. There are two different quadrupeds: sprawling and

mammal-type.(Kitano et al., 2016). Mammals, for example, dogs or cats, biologically inspired

the mammal type quadruped. The joints are underneath the body of the robot and their limbs are

shoulder-width apart. This type of robot is popular because of its cost-efficiency. Sprawling-type

quadrupeds are like spiders, but with fewer legs. The legs come up from the body and then down towards the floor, and the distance between the limbs and the body is wider. This makes the

robot’s center of mass lower, which gives the added benefit of the robot being more stable

(Kitano et al., 2016). There are other types of walking robots with more legs, such as hexapods,

but they are costly and less energy-efficient. Gong et al., (2018) found that quadrupedal robots

are more stable and capable of carrying heavier loads compared to one-legged and biped robots.

Current Innovations in Quadruped Robots

Although there is more focus on the research of walking robots, they are not a new

concept. Chebyshev invented the first walking robot in the 1800s and the first autonomous

quadruped robot was created in 1960, called the “phony pony”, in California (Biswal &

Mohanty, 2020). The fastest quadruped robot was the Cheetah by Boston Dynamics in 2013.

They made a new mini Cheetah created by MIT in 2021, and it is the first to do a backflip (Zewe,

2021). The robot’s flexibility and speed are useful, but its leaping ability is even more

fascinating. Not only that, but it also uses a two-part controller; one controller controls the robot

while the other one is a neutral controller that takes in the ground’s view and “learns” from

experience. The robot then gets both benefits of blind robots (robots without any cameras or

sensors) and improves on robots that would need a map of the area first (Zewe, 2021). The new

smallest walking robot is a microscopic insect-like robot that has various gaits and can even

jump (Morris, 2022). Its small build can be very helpful in biology, especially in studying small

ecosystems and insects. The most interesting thing, however, is not its size, but the way it moves.

Instead of using electricity, the tiny robot is made using an alloy which bends when heated. By

rapidly and repeatedly heating the robot, they can make the robot walk. The scientist put a glass

on the robot to help the alloy return to its shape (Morris, 2022). TITAN XIII, the newest

quadruped of the series, is a battery-powered sprawling quadruped robot that can walk efficiently at 1.38 m/s speed (Biswal & Mohanty, 2020). Walking robots have proven their ability to be used

in situations such as inspections. The ANYmal could navigate through an oil site and measure

different gauges, and the position of valve handles(Bellicoso et al., 2018). These inspections

improve the health and safety of the worksite as well as improve efficiency and production.

Energy Efficiency

Specific resistance measures the energy-efficiency of a robot. It is the ratio of the amount

of energy in Joules over the gravitational potential energy of the robot, if somebody raised it by

the distance the robot walked. (E/Mgd). Another formula is power in watts divided by the mass

times the gravitational field strength times velocity. (P/Mgv)This is equivalent to the cost of

transport (Kajita & Espianu, 2018). The formula accounts for mass, gravity, distance, and surface

friction to calculate the total energy used for movement (Xiao & Whittaker, 2014). There have

been numerous designs to lower the energy consumption of walking robots. For example, a

robot, made by Wong et al., uses springs up and down the robot’s legs to replicate how living

things absorb the shock of stepping. However, the robot is still not as efficient as animals or

people. The Walkman robot shows a maximum consumption of 368 W, having an SR of 1.35.

The SR is seven times higher than a person walking. (Kashmiri et al., 2018.)

Wireless Connection

The ESP32 CAM can connect wirelessly to other devices using either Bluetooth or

Wi-Fi. Wireless connection works by sending and receiving data between devices using radio

waves (Anniss, 2014, p.5). Although Bluetooth is the common and cheaper option, it lacks range.

So instead, the controller uses Wi-Fi to control the robot. (Katona & Kovari, 2016). Wi-Fi is a

type of wireless local area network (WLAN) that can cover at least a hundred meters (Banerji &

Chowdhury, 2013). A web server is how multiple devices connect. One device acts as an access point (AP), which creates and hosts the WLAN, and other devices that connect to the host are

clients. In this case, the ESP32 CAM acts as the access point for the WLAN, and the computer

and the ESP WROOM are the clients. The WLAN allows the computer to control the robot via

the website, sending the information back to the host, where it is then sent to the microcontroller

that controls the servo motors.

Related Studies

The NASA Jet Propulsion Laboratory, the California Institute of Technology, and

CoSTAR are currently exploring ways to map and explore Martian caves using autonomous

robots. One of these autonomous robots is none other than Boston Dynamics Spot, which is one

of the quadruped robots previously mentioned (Bourman et al. 2020). Back in 2020, Bouman et

al. used the DARPA Subterranean Challenge, a robotics competition, as a way to test the ability

of legged robots that were integrated with NeBULA autonomy, to map areas and complete

complex tasks. They even won first place in the DARPA Subterranean Challenge in 2020.

Conclusion

For now, the energy-efficiency of walking robots pales in comparison to wheeled robots

or living things. Many designs for a more energy-efficient robot have been made, in hopes that

they will be used for research or rescue. There should be more research on using Wi-Fi to control

walking robots. Many robots that use a wireless connection to control the robot were wheeled.

This design benefited from the research on the cost of transportation. Understanding the meaning

behind the cost of transportation and how to measure it will help to compare to previous designs.

Research on wireless connection was relevant as the ESP32-CAM acts as the access point for the

computer. In the future, more research on self-correcting autonomous robots will have to be

made to correct the drift that the robot experiences.

Materials

- 8 Tiankong Rc MG90S micro servo

motors with servo horns

- 1 ESP32 WROOM with 38 pins
- 1 ESP32 breakout board
- 1 switch
- 4 1.5v keeppower rechargeable

batteries

- 1 3D Printer with PLA Filament
- 22 gauge wire
- 1 laptop
- 1 Micro USB cable
- 1 #0 Phillip screwdriver
- 16 #0-80 x ¾ in. Panhead Phillip

screws

- 8 #0-80 x 1/8 in. Panhead Phillip

screws

- 1 drill with a Philip drill bit
- 1 battery mount with 4 cells
- 2 25-pin circuit boards
- 1 roll of electrical tape
- 1 roll of masking tape
- 1 scale
- 1 multimeter
- 1 stopwatch

Design Plan

Walking robots are able to deal with unpredictable and irregular terrain. However, to

create the perfect robot for exploration or search and rescue, it must obtain certain goals. Firstly,

it must be energy-efficient, as the battery must be able to last for long periods of time between

charges. Secondly, it must be small and lightweight, allowing it to go into spaces that may be too

small for a person. The size and weight will also affect the battery-life of the robot. The robot

must be user-friendly and easy to control, for example, wirelessly through the website. Lastly,

the robot must have a camera to explore caves or look for survivors and send the video feed to

the app in real time.

Table 1.1

Design Criteria | What Makes Up this Design Criteria | Importance on a Scale of 1-5
Functionality of Robot/Website | ● The robot is able to walk for at least 10 seconds. ● The robot walks in the direction dictated by the website. ● Camera sends a video feed in real time to the website. | 5
Energy-Efficiency | ● The robot has a median cost of transportation of around .15 or less ● The cost of transportation is precise. | 4

Table 1.1 shows the design criteria of the walking quadruped robot.

Part A: Assembling the Robot

Figure 1.1

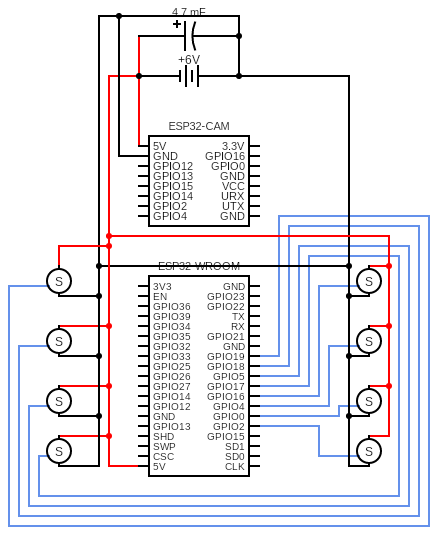
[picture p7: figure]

Figure 1.1 is a circuit schematic of the walking robot. Red is power, black is ground, and blue is

signal.

1.

Design Results

Table 1.2

Design A
| Distance (m) | Time (s) | Velocity(m/s) | CoT
Trial 1 | 0.592 | 419 | 0.001 | 3.44E-07
Trial 2 | 1.365 | 791 | 0.002 | 2.23E-07
Trial 3 | 0.145 | 266 | 0.001 | 2.09E-07
Trial 4 | 0.325 | 213 | 0.002 | 7.31E-07
Trial 5 | 0.396 | 186 | 0.002 | 1.17E-06
Mean | 0.565 | 375.0 | 0.002 | 5.35E-07
SD | 0.425 | 223.1 | 0.000 | 3.69E-07
SE | 0.245 | 128.8 | 0.000 | 2.13E-07

Table 1.2 shows the distance walked in meters, the velocity, and the cost of transportation across

five trials.

Figure 1.3

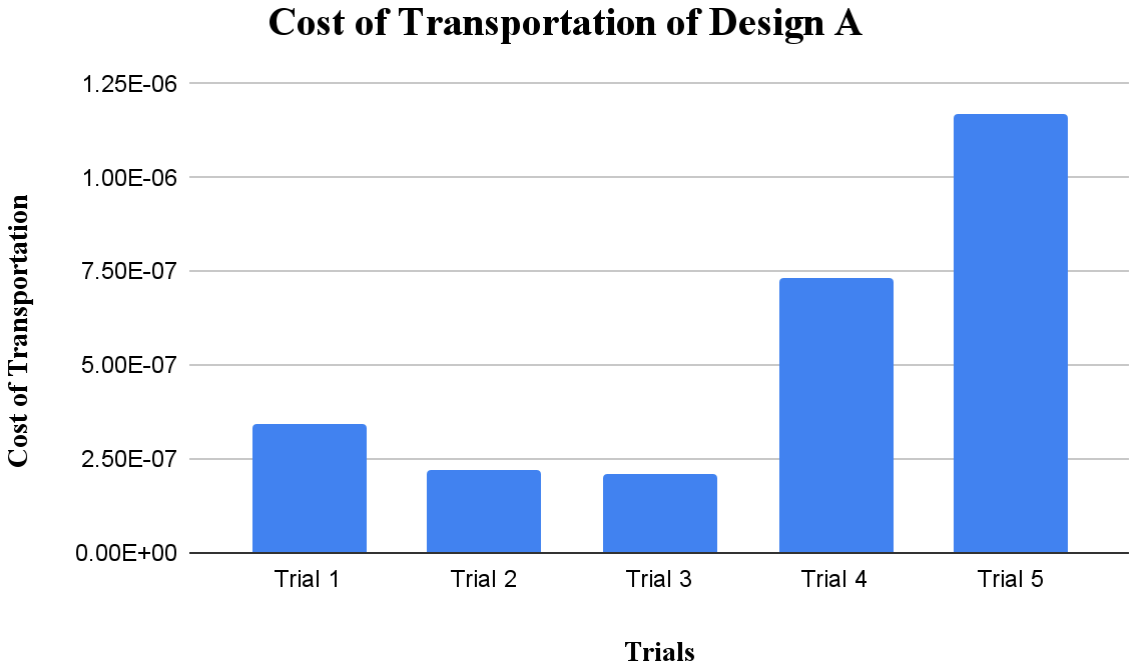
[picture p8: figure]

Figure 1.3 shows the cost of transportation of Design A through five trials.

Table 1.3

Design Criteria | What Makes Up this Design Criteria | Completion on a Scale of 1-5
Functionality of Robot/App | ● The robot is able to walk for at least 10 seconds. ● The robot walks in the direction dictated by the app. ● Camera sends a video feed in real time to the app. | 5

Energy-Efficiency | ● The robot has a median cost of transportation of around .15 or less ● The cost of transportation is precise.
5

Table 1.3 shows the completion of the design criteria for Design A.

Redesign Plan

The legs of the robot would slightly splay outwards. A reason could be that there is too

much force on the legs, and the heavier, longer body was too much for the stubby legs. When

designing the legs, the new design took the measurements from the previous model. However,

the body of this prototype is much longer and wider due to there being two microcontrollers

inside the robot. Luckily, there is a simple solution. All that needs to be done is to redesign the

legs to have more support at the bottom and to be longer.

Part D: Redesign

1. Access the 3D model of the shell of the legs.

https://www.tinkercad.com/things/6SStwJWXF3I

2. Remove the legs from the servo motors.
3. Attach the new legs onto the servo motors and screw them into place.

Redesign Results

Table 1.4

Design B
| Distance (m) | Time (s) | Velocity(m/s) | CoT
Trial 1 | 0.120 | 16 | 0.008 | 4.78E-05
Trial 2 | 0.049 | 13 | 0.004 | 5.58E-05
Trial 3 | 0.095 | 32 | 0.003 | 9.47E-06
Trial 4 | 0.081 | 12 | 0.007 | 5.74E-05
Trial 5 | 0.115 | 29 | 0.004 | 1.40E-05
Mean | 0.09 | 20.40 | 0.005 | 3.69E-05
SD | 0.03 | 8.40 | 0.002 | 2.08E-05
SE | 0.01 | 4.85 | 0.001 | 1.20E-05

Table 1.4 shows the distance in meters, the velocity, and the cost of transportation across five

trials.

Figure 1.4

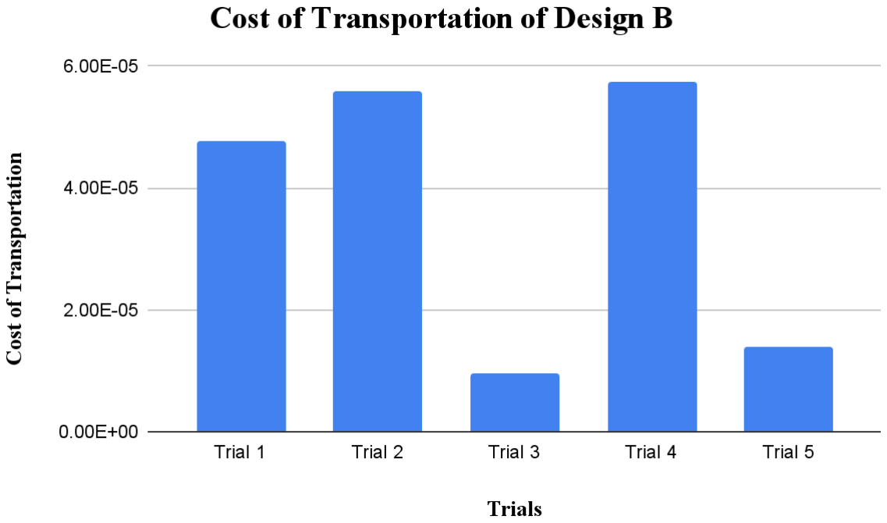
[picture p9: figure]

Figure 1.4 shows the cost of transportation of Design B across five trials.

Table 1.5

The Effect of Distance (m) and Time (s) on the Cost of Transport
Design A | Design B
Distance
(m) Time (s)

Velocity(
m/s) CoT

Distance
(m) Time (s)

Velocity(
m/s) | CoT
Trial 1 | 0.592 | 419 | 0.001 3.44E-07 0.120 | 16 | 0.008 4.78E-05
Trial 2 | 1.365 | 791 | 0.002 2.23E-07 0.049 | 13 | 0.004 5.58E-05
Trial 3 | 0.145 | 266 | 0.001 2.09E-07 0.095 | 32 | 0.003 9.47E-06
Trial 4 | 0.325 | 213 | 0.002 7.31E-07 0.081 | 12 | 0.007 5.74E-05
Trial 5 | 0.396 | 186 | 0.002 1.17E-06 | 0.115 | 29 | 0.004 1.40E-05
Mean | 0.565 | 375.0 | 0.002 5.35E-07 | 0.09 | 20.40 | 0.005 3.69E-05
SD | 0.425 | 223.1 | 0.000 3.69E-07 | 0.03 | 8.40 | 0.002 2.08E-05
SE | 0.245 | 128.8 | 0.000 2.13E-07 | 0.01 | 4.85 | 0.001 1.20E-05

Table 1.5 shows the distance, the velocity, and cost of transportation of design A and design B.

Figure 1.5

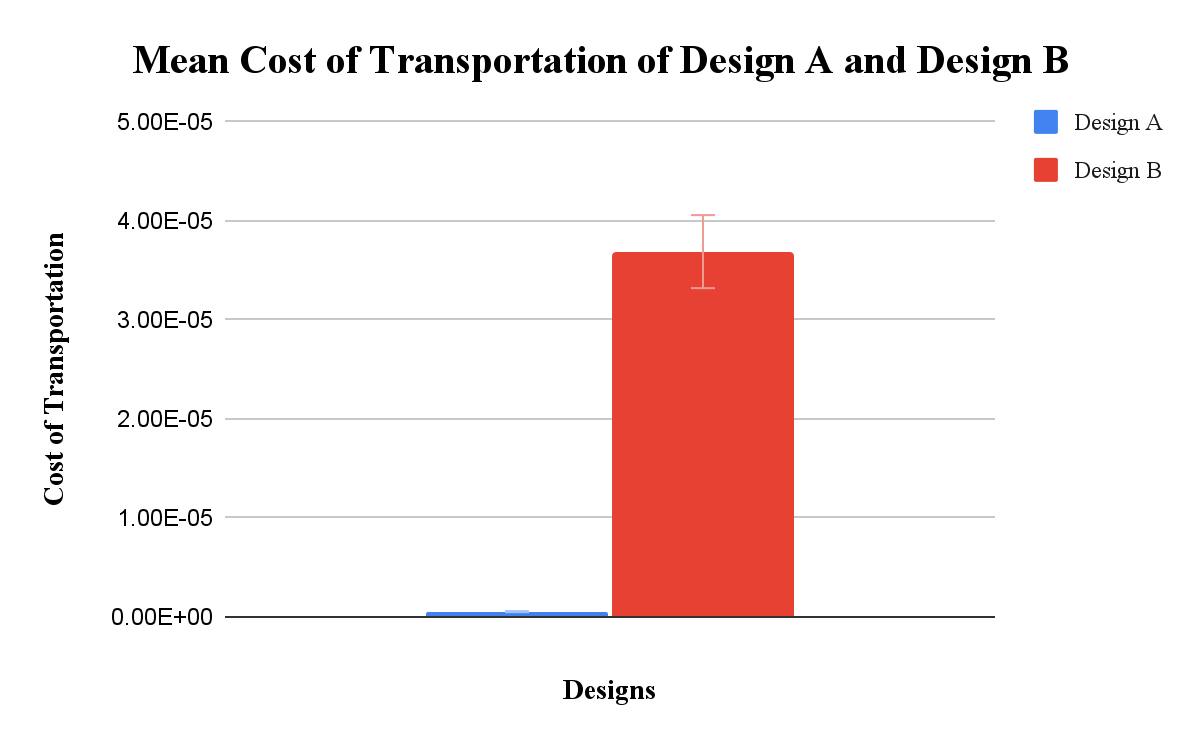
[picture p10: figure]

Figure 1.5 shows the mean cost of transportation between the two designs.

Table 1.6

Design Criteria | What Makes Up this Design Criteria | Completion on a Scale of 1-5
Functionality of Robot/App | ● The robot is able to walk for at least 10 seconds. ● The robot walks in the direction dictated by the app. ● Camera sends a video feed in real time to the app. | 4

Energy-Efficiency | ● The robot has a median cost of transportation of around .15 or less ● The cost of transportation is precise.
5

Table 1.6 shows the completion of the design criteria for Design B.

Conclusion

The redesign was in fact worse than the initial design. The motors constantly failed, and

the legs were popping off more. The cost of transportation was also worse, as the redesign had a

mean Cost of Transportation of 3.69E-5, compared to the initial design having a mean Cost of

Transportation of 5.35E-7. I believe that the reason that the robot struggled to walk and had a

greater Cost of Transportation when it had the longer legs is due to weight. When designing the

legs, the top part was very thick to enclose the wires and the servo motors, which was why the

legs were popping off the servo motors. Increasing the length of the legs also meant an increase

in mass that the servo motors had to move. That meant that the servo motors had to use more

force to move the legs, and when the servo was unable to move the legs, it would lead to all the

motors failing. This also explains why the Cost of Transportation was worse in the redesign,

because the robot had to do more work, but couldn’t walk for even a minute, the power was

larger than in the initial design, and while the redesign was heavier than the initial design

(0.530kg and 0.500kg respectively), and the velocity of the redesign was greater, due to the

larger legs, in the end, it was great enough for it to be as energy-efficient as the initial design.

There are a few issues to note. For example, because the redesign couldn’t walk with the

protective cover on top, both designs were massed and tested without the protective cover.

Another error is that instead of recharging the batteries after each trial, the trials were run

consecutively. That means that over time, the motors slowly became weaker. It is most evident in

the later trials of the initial design. Another issue was that the robot had a tendency to drift to the

left or right, the distance walked might be slightly greater than the recorded distance. Human

error should also be taken into account when it comes to the time, as the stopwatch may have not started or stopped at the exact same time the robot begins moving forward or when it

experienced a failure.

The purpose of this design was to create an energy-efficient walking quadruped robot that

would be able to aid in exploration, but the camera and website could be used for more than just

cave exploration. For example, companies could use walking robots with cameras for

inspections, as some already have begun doing. The website is easily customizable to fit various

tasks. The camera itself has a variety of functions, for example, the camera comes pre-equip with

facial detection AI. The camera’s compatibility with AI has led to an upcoming design

investigation to have the robot run autonomously and use the camera with AI to detect the

distance between obstacles.

Next year, during the pursuit of an autonomous walking robot, the top section of the legs

will be made thinner to avoid the issue of the legs popping off, as this wasn’t an issue that last

year’s design investigation had, and it had thinner legs. Researching AI will be important for

next year’s project. Next year’s project will develop both the autonomous, but blind, robot from

the previous year and the current camera-equipped robot that relies on user input into a robot

with the ability to both run by itself and observe its surroundings.

Reference List

Anniss, M. (2014) How does Wifi work? Gareth Stevens Publishing.

https://www.google.com/books/edition/How_Does_WiFi_Work/FotfEAAAQBAJ?hl=en&

gbpv=0

Banerji, S. & Chowdhury, R. S. (2013) On ieee 802.11: Wireless lan technology. International

Journal of Mobile Network Communications & Telematics (IJMNCT)

Vol. 3, Issue. 4, 2013. 10.5121

Bellicoso, D., Bjelonic, M., Wellhausen, L. & Holtmann, K. (2018) Advances in real-world

applications for legged robots. Journal of Field Robotics.10.1002/rob.21839

Biswal, P. & Mohanty P. K. (2020). Development of quadruped walking robots: A review. Ain

Shams Engineering Journal, 12(2).10.1016 (https://doi.org/10.1016/j.asej.2020.11.005)

Bouman et al. (2020) Nebula: Team costar’s robotic autonomy solution that won phase II of

darpa subterranean challenge. “Field robotics”, March 2022, vol. 2, p.

1432-1506.10.55417

Gong, D., Wang, P., Zhao, S., Du, L. & Duan, Y. (2018) Bionic quadruped robot dynamic gait

control strategy based on twenty degrees of freedom. IEEE. 10.1109/JAS.2017.7510790

Kajita, S. & Espiau, B. (2018) Legged Robots. Handbook of robotics. (361-389) Springer.

978-3-319-32552-1

Katona, J. & Kovari, A. (2016). Cost-effective wifi controlled mobile robot. 11th International

Symposium on Applied Informatics and Related Areas.

https://www.researchgate.net/profile/Jozsef-Katona/publication/310600119_Cost-effectiv

e_WiFi_controlled_mobile_robot/links/5b3a5423a6fdcc8506ea375f/Cost-effective-WiFi-

controlled-mobile-robot.pdf

Kashiri et al. (2018) An Overview on Principles for Energy Efficient Robot Locomotion.

Advances in Mechatronics and Biomechanics towards Efficient Robot Actuation.

https://doi.org/10.3389/frobt.2018.00129

Kitano, S., Hirose, S., Horigome, A. & Endo, G. (2016) Titan-XIII: Sprawling-type quadruped

robot with ability of fast and energy-efficient walking. ROBOMECH Journal, 3(8).

https://doi.org/10.1186/s40648-016-0047-1

Morris, A. (2022) Tiny robotic crab is smallest-ever remote-controlled walking robot.

Northwestern.

https://news.northwestern.edu/stories/2022/05/tiny-robotic-crab-is-smallest-ever-remote-

controlled-walking-robot/

Ortiz, J. H. & Vinjamuri R. (2021) Collaborative and humanoid robots. Intech Open.

https://www.google.com/books/edition/_/GtJGEAAAQBAJ?hl=en&gbpv=0

Todd, D. J. (2013). Walking machines. Springer

US.https://www.google.com/books/edition/Walking_Machines/zb_SBwAAQBAJ?hl=en

&gbpv=0 (https://www.google.com/books/edition/Walking_Machines/zb_SBwAAQBAJ?hl=en&gbpv=0)

Westcott, S., & Westcott J. R. (2020) Basic electronics: Theory and practice. Mercury Learning

and

Information.https://www.google.com/books/edition/Basic_Electronics/mkbrDwAAQBAJ

?hl=en&gbpv=0

Wong, L. H., Sivanesan, S., M F A Faisol, Othman, W., Wahab, A. & Alhady, S. (2021)

Development of quadruped walking robot with passive compliance legs using XL4005

buck converter. Journal of Physics: Conference Series, 1969(), 26-27.

https://doi.org/10.1088/1742-6596/1969/1/012003

Xiao, X. & Whittaker, W. L. (2014) Energy considerations for wheeled mobile robots operating

on a single battery discharge. Carnegie Mellon University.

https://www.ri.cmu.edu/pub_files/2014/8/TR-14-16.pdf

Zewe, A. (2021). One giant leap for the mini cheetah: A new control system, demonstrated using

MIT’s robotic mini cheetah, enables four-legged robots to jump across uneven terrain in

real-time. MIT News. https://news.mit.edu/2021/one-giant-leap-mini-cheetah-1020

Appendix

ESP32-CAM Complete code:

//All my code was uploaded to my repository at //https://github.com/bsverdin/Walking-Robot.//Libraries
#include "esp_camera.h"

#include <WiFi.h>

#include "esp_wifi.h"

#include "esp_timer.h"

#include "img_converters.h"

#include "Arduino.h"

#include "fb_gfx.h"

#include "soc/soc.h" | // disable brownout problems

#include "soc/rtc_cntl_reg.h" | // disable brownout problems

#include "esp_http_server.h"

#include <esp_now.h>

int int_value = 0;
// WiFi Password
const char *ssid1 = "VinnieWiFi";
const char *password1 = "Qwerty123!";
//ESP32-WROOM MAC ADDRESS
uint8_t broadcastAddress[] = { 0xE0, 0x5A, 0x1B, 0xAC, 0x5A, 0xF8 }; #define PART_BOUNDARY "123456789000000000000987654321"
#define CAMERA_MODEL_AI_THINKER

#define PWDN_GPIO_NUM | 32

#define RESET_GPIO_NUM | -1

#define XCLK_GPIO_NUM | 0

#define SIOD_GPIO_NUM | 26

#define SIOC_GPIO_NUM | 27

#define LED_BUILTIN | 4

#define Y9_GPIO_NUM | 35

#define Y8_GPIO_NUM | 34

#define Y7_GPIO_NUM | 39

#define Y6_GPIO_NUM | 36

#define Y5_GPIO_NUM | 21

#define Y4_GPIO_NUM | 19

#define Y3_GPIO_NUM | 18

#define Y2_GPIO_NUM | 5

#define VSYNC_GPIO_NUM | 25

#define HREF_GPIO_NUM | 23

#define PCLK_GPIO_NUM | 22

//ESP NOW
typedef struct struct_message { int b;
} struct_message;
struct_message myData;
esp_now_peer_info_t peerInfo;
void OnDataSent(const uint8_t *mac_addr, esp_now_send_status_t status) { Serial.print("\r\nLast Packet Send Status:\t");
Serial.println(status == ESP_NOW_SEND_SUCCESS ? "Delivery Success" : "Delivery Fail");
}
static const char* _STREAM_CONTENT_TYPE = "multipart/x-mixed-replace;boundary=" PART_BOUNDARY;
static const char* _STREAM_BOUNDARY = "\r\n--" PART_BOUNDARY "\r\n"; static const char* _STREAM_PART = "Content-Type: image/jpeg\r\nContent-Length: %u\r\n\r\n";

httpd_handle_t camera_httpd = NULL;
httpd_handle_t stream_httpd = NULL;

static const char PROGMEM INDEX_HTML[] = R"rawliteral( <html>
<head>
<title>Vinnie</title>
<meta name="viewport" content="width=device-width, initial-scale=1"> <style>
body { font-family: Arial; text-align: center; margin:0px auto; padding-top: 30px;}
table { margin-left: auto; margin-right: auto; }
td { padding: 8 px; }
.button {
background-color: #8563e7;
border: none;
color: white;
padding: 10px 20px;
text-align: center;
text-decoration: none;

display: inline-block;
font-size: 18px;
margin: 6px 3px;
cursor: pointer;
-webkit-touch-callout: none; -webkit-user-select: none; -khtml-user-select: none;
-moz-user-select: none;
-ms-user-select: none;
user-select: none;
-webkit-tap-highlight-color: rgba(0,0,0,0); }
img { width: auto ;
max-width: 100% ;
height: auto ;
}
</style>
</head>
<body>
<h1>Walking Exploration Robot</h1>
<img src="" id="photo" >
<table>
<tr><td colspan="3" align="center"><button class="button" onmousedown="toggleCheckbox('forward');" ontouchstart="toggleCheckbox('forward');" onmouseup="toggleCheckbox('stop');" ontouchend="toggleCheckbox('stop');">Forward</button></td></tr>
<tr><td align="center"><button class="button" onmousedown="toggleCheckbox('left');" ontouchstart="toggleCheckbox('left');" onmouseup="toggleCheckbox('stop');" ontouchend="toggleCheckbox('stop');">Left</button></td><td align="center"><button class="button" onmousedown="toggleCheckbox('stop');" ontouchstart="toggleCheckbox('stop');">Stop</button></td><td align="center"><button class="button" onmousedown="toggleCheckbox('right');" ontouchstart="toggleCheckbox('right');" onmouseup="toggleCheckbox('stop');" ontouchend="toggleCheckbox('stop');">Right</button></td></tr>

<tr><td colspan="3" align="center"><button class="button" onmousedown="toggleCheckbox('backward');" ontouchstart="toggleCheckbox('backward');" onmouseup="toggleCheckbox('stop');" ontouchend="toggleCheckbox('stop');">Backward</button></td></tr> <tr><td></td><td align="center"><button class="button button4" id="flash" onmousedown="toggleCheckbox('flash');" ontouchstart="toggleCheckbox('flash');" onmouseup="toggleCheckbox('flashoff');" ontouchend="toggleCheckbox('flashoff');">Flash</button></td><td></td></tr> </table>
<script>
function toggleCheckbox(x) {
var xhr = new XMLHttpRequest(); xhr.open("GET", "/action?go=" + x, true); xhr.send();
}
window.onload = document.getElementById("photo").src = window.location.href.slice(0, -1) + ":81/stream"; </script>
</body>
</html>
)rawliteral";

static esp_err_t index_handler(httpd_req_t *req){ httpd_resp_set_type(req, "text/html");
return httpd_resp_send(req, (const char *)INDEX_HTML, strlen(INDEX_HTML));
}

static esp_err_t stream_handler(httpd_req_t *req){ camera_fb_t * fb = NULL;
esp_err_t res = ESP_OK;
size_t _jpg_buf_len = 0;
uint8_t * _jpg_buf = NULL;
char * part_buf[64];

res = httpd_resp_set_type(req, _STREAM_CONTENT_TYPE); if(res != ESP_OK){
return res;

}

while(true){
fb = esp_camera_fb_get();
if (!fb) {
Serial.println("Camera capture failed"); res = ESP_FAIL;
} else {
if(fb->width > 400){
if(fb->format != PIXFORMAT_JPEG){
bool jpeg_converted = frame2jpg(fb, 80, &_jpg_buf, &_jpg_buf_len);
esp_camera_fb_return(fb);
fb = NULL;
if(!jpeg_converted){
Serial.println("JPEG compression failed"); res = ESP_FAIL;
}
} else {
_jpg_buf_len = fb->len;
_jpg_buf = fb->buf;
}
}
}
if(res == ESP_OK){
size_t hlen = snprintf((char *)part_buf, 64, _STREAM_PART, _jpg_buf_len);
res = httpd_resp_send_chunk(req, (const char *)part_buf, hlen); }
if(res == ESP_OK){
res = httpd_resp_send_chunk(req, (const char *)_jpg_buf, _jpg_buf_len);
}
if(res == ESP_OK){
res = httpd_resp_send_chunk(req, _STREAM_BOUNDARY, strlen(_STREAM_BOUNDARY));
}
if(fb){
esp_camera_fb_return(fb);
fb = NULL;

_jpg_buf = NULL;
} else if(_jpg_buf){
free(_jpg_buf);
_jpg_buf = NULL;
}
if(res != ESP_OK){
break;
}
//Serial.printf("MJPG: %uB\n",(uint32_t)(_jpg_buf_len)); }
return res;
}

static esp_err_t cmd_handler(httpd_req_t *req){ char* buf;
size_t buf_len;
char variable[32] = {0,};

buf_len = httpd_req_get_url_query_len(req) + 1; if (buf_len > 1) {
buf = (char*)malloc(buf_len);
if(!buf){
httpd_resp_send_500(req);
return ESP_FAIL;
}
if (httpd_req_get_url_query_str(req, buf, buf_len) == ESP_OK) {
if (httpd_query_key_value(buf, "go", variable, sizeof(variable)) == ESP_OK) {
} else {
free(buf);
httpd_resp_send_404(req);
return ESP_FAIL;
}
} else {
free(buf);
httpd_resp_send_404(req);
return ESP_FAIL;
}
free(buf);
} else {

httpd_resp_send_404(req);
return ESP_FAIL;
}

sensor_t * s = esp_camera_sensor_get(); int res = 0;

if (!strcmp(variable, "flash")) { Serial.println("Flash On"); pinMode(LED_BUILTIN, HIGH);

} else if (!strcmp(variable, "flashoff")) { Serial.println("Flash Off"); pinMode(LED_BUILTIN, LOW);
}
if(!strcmp(variable, "forward")) { Serial.println("Forward"); int_value = 1;
// Set values to send
myData.b = int_value;
// Send message via ESP-NOW
esp_err_t result = esp_now_send(broadcastAddress, (uint8_t *) &myData, sizeof(myData));

if (result == ESP_OK) {
Serial.println("Sending confirmed"); }
else {
Serial.println("Sending error");
}
} else if (!strcmp(variable, "left")) { Serial.println("Left");
int_value = 2;
// Set values to send
myData.b = int_value;
// Send message via ESP-NOW
esp_err_t result = esp_now_send(broadcastAddress, (uint8_t *) &myData, sizeof(myData));

if (result == ESP_OK) {
Serial.println("Sending confirmed"); }
else {
Serial.println("Sending error");
}
} else if (!strcmp(variable, "right")) { Serial.println("Right");
int_value = 3;
// Set values to send
myData.b = int_value;
// Send message via ESP-NOW
esp_err_t result = esp_now_send(broadcastAddress, (uint8_t *) &myData, sizeof(myData));

if (result == ESP_OK) {
Serial.println("Sending confirmed"); }
else {
Serial.println("Sending error");
}
} else if (!strcmp(variable, "backward")) { Serial.println("Backward");
int_value = 4;
// Set values to send
myData.b = int_value;
// Send message via ESP-NOW
esp_err_t result = esp_now_send(broadcastAddress, (uint8_t *) &myData, sizeof(myData));

if (result == ESP_OK) {
Serial.println("Sending confirmed"); }
else {
Serial.println("Sending error");
}
} else if (!strcmp(variable, "stop")) { Serial.println("Stop");
int_value = 5;
// Set values to send

myData.b = int_value;
// Send message via ESP-NOW
esp_err_t result = esp_now_send(broadcastAddress, (uint8_t *) &myData, sizeof(myData));

if (result == ESP_OK) {
Serial.println("Sending confirmed"); }
else {
Serial.println("Sending error");
}
} else {
res = -1;
}

if(res){
return httpd_resp_send_500(req);
}

httpd_resp_set_hdr(req, "Access-Control-Allow-Origin", "*"); return httpd_resp_send(req, NULL, 0);
}

void startCameraServer(){
httpd_config_t config = HTTPD_DEFAULT_CONFIG(); config.server_port = 80;
httpd_uri_t index_uri = {
.uri | = "/",
.method | = HTTP_GET,
.handler | = index_handler,
.user_ctx = NULL
};

httpd_uri_t cmd_uri = {
.uri | = "/action",
.method | = HTTP_GET,
.handler | = cmd_handler,
.user_ctx = NULL
};
httpd_uri_t stream_uri = {

.uri | = "/stream",
.method | = HTTP_GET,
.handler | = stream_handler,
.user_ctx = NULL
};
if (httpd_start(&camera_httpd, &config) == ESP_OK) { httpd_register_uri_handler(camera_httpd, &index_uri); httpd_register_uri_handler(camera_httpd, &cmd_uri); }
config.server_port += 1;
config.ctrl_port += 1;
if (httpd_start(&stream_httpd, &config) == ESP_OK) { httpd_register_uri_handler(stream_httpd, &stream_uri); }
}

void setup() {
WRITE_PERI_REG(RTC_CNTL_BROWN_OUT_REG, 0); //disable brownout detector Serial.begin(115200);
Serial.setDebugOutput(false);
// Set device as a Wi-Fi Station
WiFi.mode(WIFI_STA);
WiFi.softAP(ssid1, password1); pinMode (LED_BUILTIN, OUTPUT);
// Init ESP-NOW
esp_now_init();
if (esp_now_init() != ESP_OK) { Serial.println("Error initializing ESP-NOW"); return;
}

// Once ESPNow is successfully Init, we will register for Send CB to // get the status of Trasnmitted packet esp_now_register_send_cb(OnDataSent);

// Register peer
memcpy(peerInfo.peer_addr, broadcastAddress, 6); peerInfo.channel = 1;
peerInfo.encrypt = false;

// Add peer
if (esp_now_add_peer(&peerInfo) != ESP_OK) { Serial.println("Failed to add peer"); return;
}

camera_config_t config;
config.ledc_channel = LEDC_CHANNEL_0; config.ledc_timer = LEDC_TIMER_0; config.pin_d0 = Y2_GPIO_NUM; config.pin_d1 = Y3_GPIO_NUM; config.pin_d2 = Y4_GPIO_NUM; config.pin_d3 = Y5_GPIO_NUM; config.pin_d4 = Y6_GPIO_NUM; config.pin_d5 = Y7_GPIO_NUM; config.pin_d6 = Y8_GPIO_NUM; config.pin_d7 = Y9_GPIO_NUM; config.pin_xclk = XCLK_GPIO_NUM; config.pin_pclk = PCLK_GPIO_NUM; config.pin_vsync = VSYNC_GPIO_NUM; config.pin_href = HREF_GPIO_NUM; config.pin_sscb_sda = SIOD_GPIO_NUM; config.pin_sscb_scl = SIOC_GPIO_NUM; config.pin_pwdn = PWDN_GPIO_NUM; config.pin_reset = RESET_GPIO_NUM; config.xclk_freq_hz = 20000000; config.pixel_format = PIXFORMAT_JPEG;

if(psramFound()){
config.frame_size = FRAMESIZE_VGA; config.jpeg_quality = 10;
config.fb_count = 2;
} else {
config.frame_size = FRAMESIZE_SVGA; config.jpeg_quality = 12;
config.fb_count = 1;
}

// Camera init
esp_err_t err = esp_camera_init(&config);

if (err != ESP_OK) {
Serial.printf("Camera init failed with error 0x%x", err); return;
}
// Wi-Fi connection
WiFi.softAP(ssid1, password1); IPAddress myIP = WiFi.softAPIP(); Serial.print("AP IP address: "); Serial.println(myIP);
// Start streaming web server startCameraServer();
}

void loop() {

}

ESP32-WROOM Complete code:

//All my code was uploaded to my repository at //https://github.com/bsverdin/Walking-Robot.//Libraries
#include <esp_now.h>

#include <ESP32Servo.h>

#include <WiFi.h>

#include "esp_wifi.h"

//Chanel
#define CHANNEL 1

//Servos
Servo shoulder1;
Servo elbow1;
Servo shoulder2;
Servo elbow2;
Servo hip3;
Servo knee3;
Servo hip4;
Servo knee4;
//Starting position based on how servos are installed int s1 = 90;
int s2 = 90;

int h3 = 90;
int h4 = 90;
int e1 = 90;
int e2 = 90;
int k3 = 90;
int k4 = 90;
//Delays
int d1 = 500;
int d2 = 1000;
int d3 = 50;
int d4 = 75;
int d5 = 100;
int d6 = 3000;
int m = 0;
//servo GPIO pins
int s1Pin = 19;
int e1Pin = 18;
int s2Pin = 5;
int e2Pin = 17;
int h3Pin = 16;
int k3Pin = 4;
int h4Pin = 2;
int k4Pin = 15;
//Methods
void walk_fwd() {
for (m = 0; m <= 12; m += 1) { knee3.write(k3 - 60 - m);
delay(15);
}
for (m = 0; m <= 30; m += 1) { hip3.write(h3 + 30 - m);
delay(15);
}
for (m = 0; m <= 24; m += 1) { knee3.write(k3 - 72 + m);
delay(15);
}
for (m = 0; m <= 30; m += 1) { hip3.write(h3 + m);
delay(15);

}
for (m = 0; m <= 12; m += 1) { knee3.write(k3 - 48 - m);
delay(15);
}
for (m = 0; m <= 12; m += 1) { elbow2.write(e2 + 60 + m); delay(15);
}
for (m = 0; m <= 30; m += 1) { shoulder2.write(s2 - 30 + m); delay(15);
}
for (m = 0; m <= 24; m += 1) { elbow2.write(e2 + 72 - m); delay(15);
}
for (m = 0; m <= 30; m += 1) { shoulder2.write(s2 - m);
delay(15);
}
for (m = 0; m <= 12; m += 1) { elbow2.write(e2 + 48 + m); delay(15);
}
for (m = 0; m <= 12; m += 1) { knee4.write(k4 + 60 + m);
delay(15);
}
for (m = 0; m <= 30; m += 1) { hip4.write(h4 - 30 + m);
delay(15);
}
for (m = 0; m <= 24; m += 1) { knee4.write(k4 + 72 - m);
delay(15);
}
for (m = 0; m <= 30; m += 1) { hip4.write(h4 - m);
delay(15);

}
for (m = 0; m <= 12; m += 1) { knee4.write(k4 + 48 + m);
delay(15);
}
for (m = 0; m <= 12; m += 1) { elbow1.write(e1 - 60 - m); delay(15);
}
for (m = 0; m <= 30; m += 1) { shoulder1.write(s1 + 30 - m); delay(15);
}
for (m = 0; m <= 24; m += 1) { elbow1.write(e1 - 72 + m); delay(15);
}
for (m = 0; m <= 30; m += 1) { shoulder1.write(s1 + m);
delay(15);
}
for (m = 0; m <= 12; m += 1) { elbow1.write(e1 - 48 - m); delay(15);
}
}
void walk_left() {
for (m = 0; m <= 12; m += 1) { knee3.write(k3 - 40 - m);
delay(0);
elbow2.write(e2 + 80 + m); delay(15);
}
for (m = 0; m <= 30; m += 1) { shoulder2.write(s2 - 50 + m); delay(0);
hip3.write(h3 + 10 - m);
delay(15);
}
for (m = 0; m <= 24; m += 1) {

knee3.write(k3 - 52 + m);
delay(0);
elbow2.write(e2 + 92 - m); delay(15);
}
for (m = 0; m <= 30; m += 1) { shoulder2.write(s2 - m);
delay(0);
hip3.write(h3 + m);
delay(15);
}
for (m = 0; m <= 12; m += 1) { knee3.write(k3 - 28 - m);
delay(0);
elbow2.write(e2 + 68 + m); delay(15);
}
for (m = 0; m <= 12; m += 1) { knee4.write(k4 + 80 + m);
delay(0);
elbow1.write(e1 - 40 - m); delay(15);
}
for (m = 0; m <= 30; m += 1) { shoulder1.write(s1 + 10 - m); delay(0);
hip4.write(h4 - 50 + m);
delay(15);
}
for (m = 0; m <= 24; m += 1) { knee4.write(k4 + 92 - m);
delay(0);
elbow1.write(e1 - 52 + m); delay(15);
}
for (m = 0; m <= 30; m += 1) { shoulder1.write(s1 + m);
delay(0);
hip4.write(h4 - m);
delay(15);

}
for (m = 0; m <= 12; m += 1) { knee4.write(k3 + 68 + m);
delay(0);
elbow1.write(e2 - 28 - m); delay(15);
}
}
void walk_right() {
for (m = 0; m <= 12; m += 1) { knee3.write(k3 - 80 - m);
delay(0);
elbow2.write(e2 + 40 + m); delay(15);
}
for (m = 0; m <= 30; m += 1) { shoulder2.write(s2 - 10 + m); delay(0);
hip3.write(h3 + 50 - m);
delay(15);
}
for (m = 0; m <= 24; m += 1) { knee3.write(k3 - 92 + m);
delay(0);
elbow2.write(e2 + 52 - m); delay(15);
}
for (m = 0; m <= 30; m += 1) { shoulder2.write(s2 - m);
delay(0);
hip3.write(h3 + m);
delay(15);
}
for (m = 0; m <= 12; m += 1) { knee3.write(k3 - 68 - m);
delay(0);
elbow2.write(e2 + 28 + m); delay(15);
}
for (m = 0; m <= 12; m += 1) {

knee4.write(k4 + 40 + m);
delay(0);
elbow1.write(e1 - 80 - m); delay(15);
}
for (m = 0; m <= 30; m += 1) { shoulder1.write(s1 + 50 - m); delay(0);
hip4.write(h4 - 10 + m);
delay(15);
}
for (m = 0; m <= 24; m += 1) { knee4.write(k4 + 52 - m);
delay(0);
elbow1.write(e1 - 92 + m); delay(15);
}
for (m = 0; m <= 30; m += 1) { shoulder1.write(s1 + m);
delay(0);
hip4.write(h4 - m);
delay(15);
}
for (m = 0; m <= 12; m += 1) { knee4.write(k3 + 28 + m);
delay(0);
elbow1.write(e2 - 68 - m); delay(15);
}
}
void walk_back() {
for (m = 0; m <= 12; m += 1) { knee4.write(k3 - 48 - m);
delay(0);
elbow1.write(e2 + 48 + m); delay(15);
}
for (m = 0; m <= 30; m += 1) { shoulder1.write(s1 - m);
delay(0);

hip4.write(h4 + m);
delay(15);
}
for (m = 0; m <= 24; m += 1) { knee4.write(k4 - 72 + m);
delay(0);
elbow1.write(e1 + 72 - m); delay(15);
}
for (m = 0; m <= 30; m += 1) { shoulder1.write(s1 - 30 + m); delay(0);
hip4.write(h4 + 30 - m);
delay(15);
}
for (m = 0; m <= 12; m += 1) { knee4.write(k4 - 60 - m);
delay(0);
elbow1.write(e1 + 60 + m); delay(15);
}
for (m = 0; m <= 12; m += 1) { knee3.write(k3 + 48 + m);
delay(0);
elbow2.write(e2 - 48 - m); delay(15);
}
for (m = 0; m <= 30; m += 1) { shoulder2.write(s2 + m);
delay(0);
hip3.write(h3 - m);
delay(15);
}
for (m = 0; m <= 24; m += 1) { knee3.write(k3 + 72 - m);
delay(0);
elbow2.write(e2 - 72 + m); delay(15);
}
for (m = 0; m <= 30; m += 1) {

shoulder2.write(s2 + 30 - m); delay(0);
hip3.write(h3 - 30 + m);
delay(15);
}
for (m = 0; m <= 12; m += 1) { knee3.write(k3 + 60 + m);
delay(0);
elbow2.write(e2 - 60 - m); delay(15);
}
}
void walk_stop() {
elbow2.write(e2 + 60);
delay(d5);
shoulder2.write(s2 - 30);
delay(d5);
knee4.write(k4 + 60);
delay(d5);
hip4.write(h4 - 30);
delay(d5);
elbow1.write(e1 - 60);
delay(d5);
shoulder1.write(s1 + 30);
delay(d5);
knee3.write(k3 - 60);
delay(d5);
hip3.write(h3 + 30);
delay(d6);
}
// WiFi Password
const char* ssid1 = "VinnieWiFi"; const char* password1 = "Qwerty123!"; // Receive data
typedef struct struct_message {
int b;
} struct_message;
struct_message myData;
// callback function that will be executed when data is received void OnDataRecv(const uint8_t* mac, const uint8_t* incomingData, int len) {
memcpy(&myData, incomingData, sizeof(myData));
Serial.println("Data Recieved");
if (myData.b == 1) {
Serial.println("Forward");
while (myData.b == 1){
walk_fwd();}
}else if (myData.b == 2) { Serial.println("Left");
while (myData.b == 2){
walk_left();}
} else if (myData.b == 3) { Serial.println("Right");
while (myData.b == 3){
walk_right();}
} else if (myData.b == 4) { Serial.println("Backward"); while (myData.b == 4){
walk_back();}
} else
Serial.println("Stop");
walk_stop();
}

void setup() {
Serial.begin(115200);
// Wi-Fi connection
WiFi.mode(WIFI_AP_STA);
WiFi.softAP(ssid1, password1, CHANNEL, 1); IPAddress myIP = WiFi.softAPIP(); WiFi.begin(ssid1, password1); Serial.println("Connected");
// Init ESP-NOW
esp_now_init();
if (esp_now_init() != ESP_OK) { Serial.println("Error initializing ESP-NOW"); return;
}

Unset
esp_now_register_recv_cb(esp_now_recv_cb_t(OnDataRecv));

hip3.attach(h3Pin); //purple hip3.write(h3);
delay(d1);
shoulder1.attach(s1Pin); //orange shoulder1.write(s1);
delay(d1);
hip4.attach(h4Pin); //grey hip4.write(h4);
delay(d1);
shoulder2.attach(s2Pin); //green shoulder2.write(s2);
delay(d1);
knee3.attach(k3Pin); //black knee3.write(k3);
delay(d1);
elbow1.attach(e1Pin); //yellow elbow1.write(e1);
delay(d1);
knee4.attach(k4Pin); //white knee4.write(k4);
delay(d1);
elbow2.attach(e2Pin); //blue elbow2.write(e2);
delay(d5);
elbow2.write(e2 + 60);
delay(d5);
shoulder2.write(s2 - 30);
delay(d5);
knee4.write(k4 + 60);
delay(d5);
hip4.write(h4 - 30);
delay(d5);
elbow1.write(e1 - 60);
delay(d5);

shoulder1.write(s1 + 30);
delay(d5);
knee3.write(k3 - 60);
delay(d5);
hip3.write(h3 + 30);
delay(d5);
}
void loop() {
}

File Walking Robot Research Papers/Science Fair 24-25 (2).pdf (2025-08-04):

Design of a Walking Cave Research Robot

Electronics

Design Investigation

_______________________________________________

Signature of Sponsoring Teacher

_______________________________________________

Signature of School Science Fair Coordinator

Bianca Verdin
Lane Tech College Prep High School Chicago, IL 60618
Grade 12

Verdin: DESIGN OF A WALKING CAVE RESEARCH ROBOT 4

Table of Contents

Acknowledgements

I want to give a big thank you to the staff and students of the University of Illinois at

Urbana-Champaign for supporting me with my science fair project, allowing me to work on both

my walking robot and the summer research that I was doing under WYSE. A special thanks to

Stephanie Ott-Monsivais for letting me borrow her soldering iron. Thank you to my mother and

father, Griselda Verdin and Salvador Verdin, for subsidising me with materials. Another thank

you to my abuela, Silvia Barron, for encouraging me, even if she wasn’t 100% sure what my

robot does. Lastly, my sincerest thanks to Mr. Berg and The Chicago-Style BotDogs. To be

completely honest, there were multiple points within working on this project that I felt the

greatest urge to give up. Between the college applications, having to take care of my grandma

after her knee replacement, recovering from my surgery for removing my wisdom teeth, and

becoming a software and electronics subteam lead, I felt the pressure to be too much. However, I

value the time Mr. Berg put into sponsoring my project, which ultimately pushed me to complete

this year’s project. As for my fellow team members, I would like to thank them for

understanding my circumstances and allowing me to step away from certain projects to work on

Science Fair. I know it isn’t easy, since we are rapidly approaching the Kick-off of Reefscape,

but I hope to dedicate myself fully during build season to make up for the lost time.

Definition of Need

NASA has been exploring the possibility of using both bipedal and quadruped walking

robots to explore and map out martian caves. However, here on Earth, the percentage of caves

that we have explored is estimated to be only 10% (Kambesis, 2007), but some researchers claim

it could be even less. Most exploration robots are drones, but drones only work when a cave has

a large space without bends. A drone couldn’t fly in a cramped tunnel with bends and turns. One

way that robots map out areas is by taking a 3D scan of an area. An important factor to consider

is the energy-efficiency of the robot. When a robot goes on a cave mission, whether here on

Earth or on Mars, the battery life must last for a long time. However, walking robots are not as

energy efficient as wheeled robots or drones are (Xiao & Whittaker, 2014). Ultimately, a small,

energy efficient, quadruped walking robot would be well suited for cave exploration. This design

will use the code created for last year’s robot to create a robot that researchers can control

remotely. The robot will collect data using an ultrasonic sensor to calculate the distance of walls

and obstacles. It will then send both a live feed of the cave from the camera and the calculated

distance of the cave walls from the robot to the operator. Not only does this allow for caves to be

viewed and surveyed without a human in the cave, but it also allows for easy maneuvering for

the robot. The website would be very user-friendly, allowing for little to no training to control the

robot, which has the added benefits of saving precious resources that could be delegated

everywhere in research.

Background Research

In the book Basic Electronics: Theory and Practice, Westcott defines electronics as

devices that control the flow of electrons (2020). Electrical and electronics engineering as a

whole studies both the storage of electrical energy and how electrical energy can be manipulated

by devices to create efficient solutions to problems society currently faces. Batteries, solar

panels, computers, and robots are all examples of devices that couldn’t have been made without

electrical and electronics engineers.

Electrical engineers have been working on ways to create ways to navigate uneven terrain.

However, these innovations are often made with the intentions of the technology being used for

researching celestial bodies, such as NASA’s collaboration with Boston Dynamics on the NeBula

project. However, back down here on Earth, most of the cave systems on Earth are unexplored .

The conditions of caves on Earth are very different from caves and craters on Mars and the

Moon, and therefore a robot designed to explore Martian caves wouldn’t be suited for the

damper Earth caves. Much of the current cave surveying technology on Earth are drones, but

their propellers make it have to squeeze into channels the way a small walking robot could.

Drones however, are much more energy efficient than current walking robots, due to their

light-weight designs. This means longer battery life, which is very crucial in missions. So, the

drone is seen as the better option currently for mapping caves on Earth.

Discussion

Walking Robots

“A walking robot is a robot with legged locomotion.” Wong et al. (2021). Walking robots

use limbs circulating through a pattern of movement instead of tracks or wheels to propel

themselves forwards. This unique way of moving allows the robot to traverse all types of terrain, both smooth and uneven. However, walking robots are more susceptible to tipping over,

especially if the gait of the robot does not match its current environment. However, adding

sensors to the robot and having the gait adjust to the environment, although difficult to do, is a

solution that many researchers are working on currently (Ortiz & Vinjamuri, 2021). A gait is the

relationship of the position of limbs at any given moment.The gait is a repeating pattern which

ultimately propels the robot forward. Ultimately, the gait affects the speed and the stability of the

robot. Static gaits have a wider area of support, but are slower than dynamic gaits (Gong et al.,

2018).

Biped vs. Quadruped Robots

Legged robots come in different types, including bipedal and quadrupedal. Biped robots

walk on two legs, like humans and birds. The higher center of mass and the smaller base of

support means that bipedal robots are incredibly unstable. Quadruped robots have twice the

amount of legs than bipedal robots. There are two different styles of quadrupeds: sprawling-type

and mammal-type (Kitano et al., 2016). For mammal-type quadrupeds, their designs are inspired

by quadruped vertebrate mammals, such as dogs or cats. The robot's joints are located beneath its

body, with its limbs spaced shoulder-width apart. This type of robot is common due to its

cost-efficiency and appealing, familiar design to audiences. Sprawling-type quadrupeds are more

similar to spiders or insects, but with fewer legs. The legs come up from the body and then down

towards the floor, and the distance between the limbs and the body is wider. This makes both the

robot’s center of mass lower and a wider base of support, which provides more stability than the

mammal-type quadrupeds (Kitano et al., 2016). There are other types of walking robots with

more legs, such as hexapods, but they are too costly and less energy-efficient for the added

support to be worth it. There is an even rarer type of walking robot, one-legged walking robots, which works like a pogo stick. They are too unstable, and not much research has been done on

one-legged walking robots because of this. Gong et al., (2018) found that quadrupedal robots are

more stable and capable of carrying heavier loads compared to one-legged and biped robots.

Current Innovations in Quadruped Robots

Walking robots have a surprisingly long history. Frank and McGhee’s “phony pony” was

the first autonomous walking quadruped robot, and it was created back in 1966, although there is

evidence for walking legged robots existing as far as the 1800’s. The Original Cheetah, designed

by Boston Dynamics back in 2013, holds the record for the fastest walking robot. Then in 2021,

with MIT, they redesigned and created a new mini cheetah which could do impressive feats, such

as a backflip (Zewe, 2021). The robot’s flexibility and speed are useful, but it is also able to leap,

which is very difficult for a walking robot. The mini cheetah has two controllers; one controller

is used to control the robot while the other one takes in the robot’s surroundings and “learns” and

“adapts”. The robot then gets both benefits of blind robots (robots with no cameras or sensors)

and robots that sense and process, all while improving on robots that would need a map of the

area first (Zewe, 2021). The new smallest walking robot is an insect-like robot that could fit on

the side of a penny (Morris, 2022). Its small build can be very helpful in biology, especially in

studying small ecosystems and insects. Debatably, the way the robot is powered is more

impressive than its microscopic size. Instead of using electricity, Rogers and his team made a

robot using an alloy which bends when heated. Repeated rapid heating causes the robot’s

walking motion. Glass pieces on the legs help the alloy return to its original shape after being

deformed (Morris, 2022). TITAN XIII, the latest in the quadruped series, is a battery-powered,

sprawling robot that walks efficiently at 1.38 m/s (Biswal & Mohanty, 2020). Walking robots are

already being used in complex and potentially hazardous situations. The ANYmal could navigate through an oil site and measure different gauges, and the position of valve handles (Bellicoso et

al., 2018). These inspections boost both safety and efficiency on the worksite, leading to

increased productivity.

Energy Efficiency

One measurement of energy-efficiency is the Cost of Transportation. It's calculated by

dividing the energy used in joules by the gravitational potential energy of the robot if lifted the

distance it walked (E/Mgd). Another way to calculate the Cost of Transportation is by using the

power in watts and dividing that by the product of the mass, velocity, and gravitational field

strength (P/Mgv). Another term for Cost of Transportation is Specific Resistance (Kajita &

Espianu, 2018). The formula takes into account variables such as the mass, gravity, distance, and

surface friction to calculate the ratio of energy used for movement (Xiao & Whittaker, 2014).

There have been numerous designs to lower the energy consumption of walking robots. One

creative solution designed by Wong et al., utilized springs up and down the robot’s legs to absorb

the shock of stepping. However, the robot is still not as efficient as living beings. Cornell’s

Walkman, the most energy-efficient walking robot, consumes 368 W, which means it has a SR of

1.35. That SR is seven times higher than the average person walking. (Kashmiri et al., 2018.)

Speleology

Speleology is the study of cave systems. A cave is a natural cavity in the Earth, which

allows water to flow from input points to output points (Gillieson, 2021). Speleology is
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

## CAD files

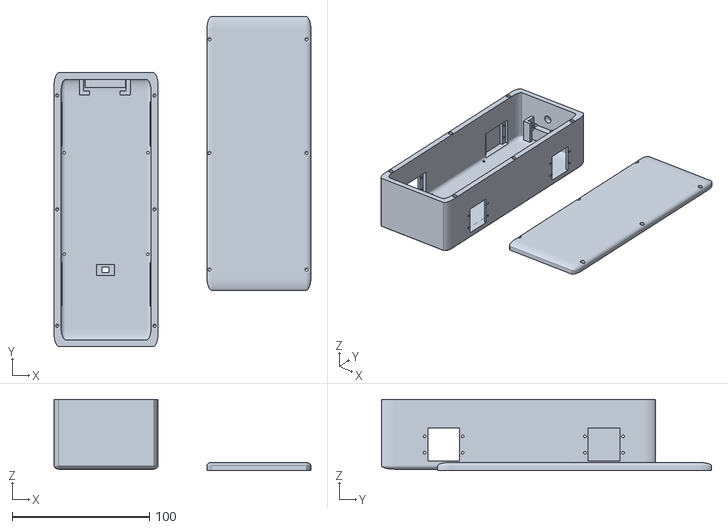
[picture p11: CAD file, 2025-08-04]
Walking Robot 3D CAD/MODEL TERRA/Terra Main Shell.stl
187.5 x 241.0 x 52.0

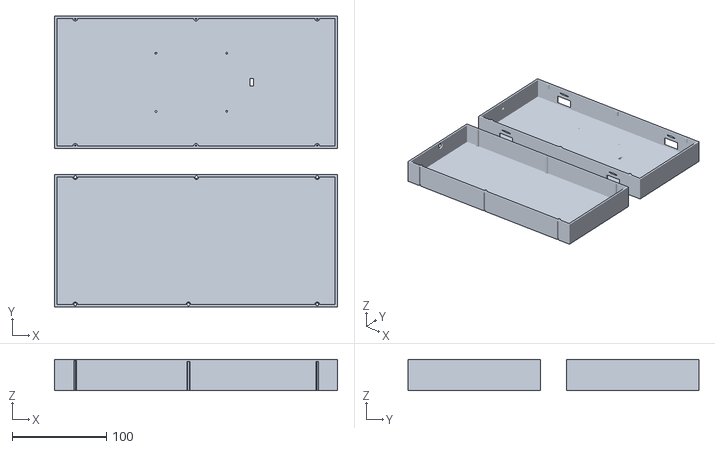
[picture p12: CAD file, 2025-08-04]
Walking Robot 3D CAD/MODEL VINNIE/Vinnie Main Shell.stl
300.0 x 308.0 x 33.0

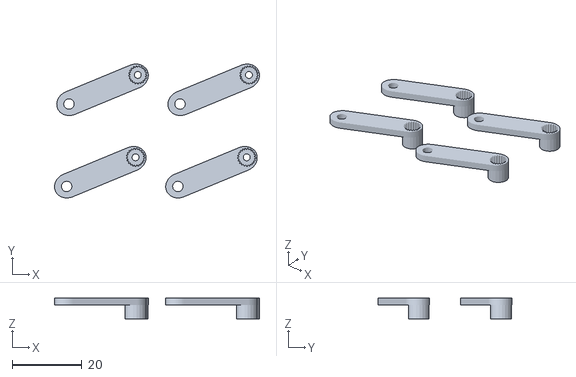
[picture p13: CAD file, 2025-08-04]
Walking Robot 3D CAD/MODEL TERRA/Terra Custom Servo Horns.stl
59.0 x 38.5 x 6.00

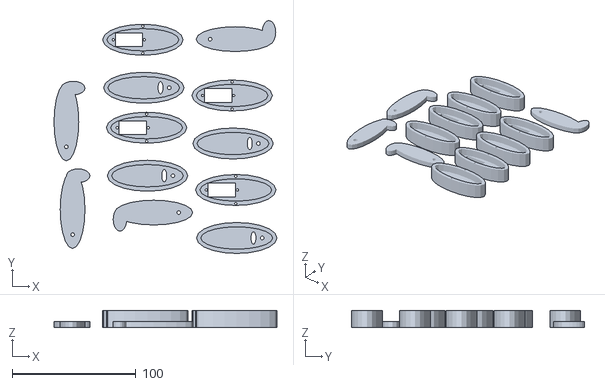
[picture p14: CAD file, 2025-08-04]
Walking Robot 3D CAD/MODEL VINNIE/Vinnie Legs (2).stl
180.0 x 188.0 x 14.0

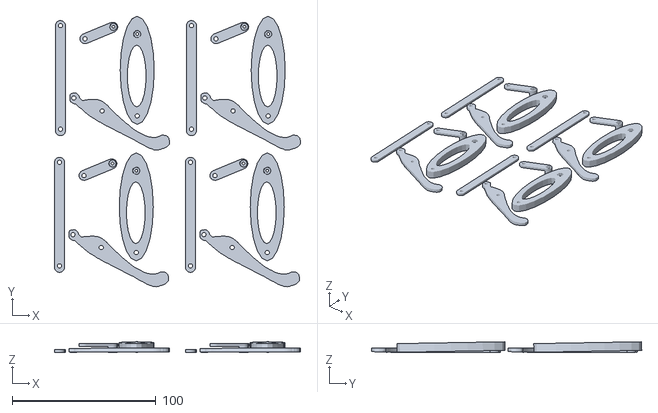
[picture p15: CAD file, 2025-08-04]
Walking Robot 3D CAD/MODEL TERRA/Terra Legs.stl
171.0 x 188.0 x 7.31
